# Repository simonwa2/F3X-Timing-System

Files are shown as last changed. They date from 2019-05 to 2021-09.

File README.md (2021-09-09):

# F3X Timing System

## About
The F3X Timing System is a wireless solution for F3F and F3B.  It has been developed and evolved over many years, primarily in response to a need to simplify event timing and management in Western Australia.  In recent years systems have been built for individuals and clubs outside of Australia.

### Simple System for Training Example
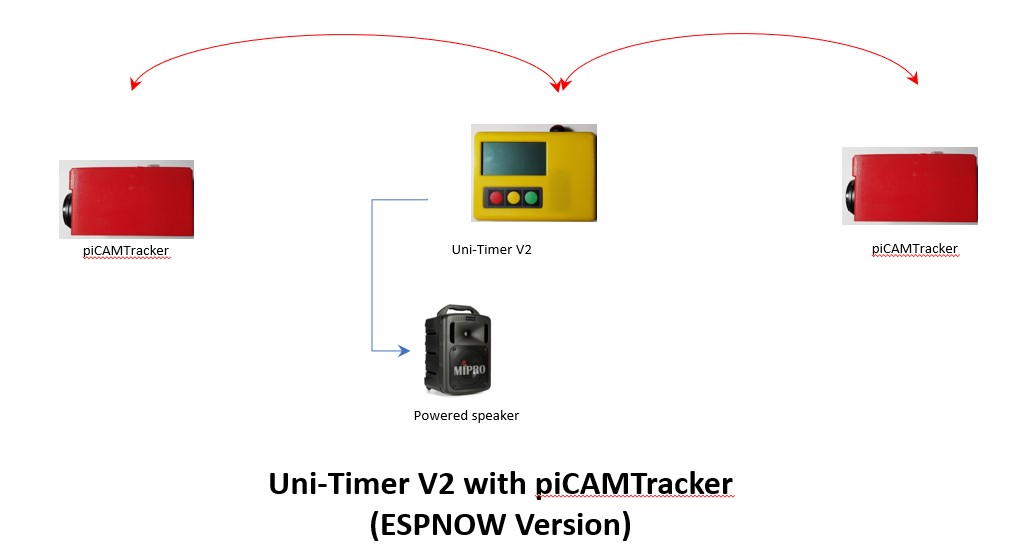
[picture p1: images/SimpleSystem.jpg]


### Full System Example
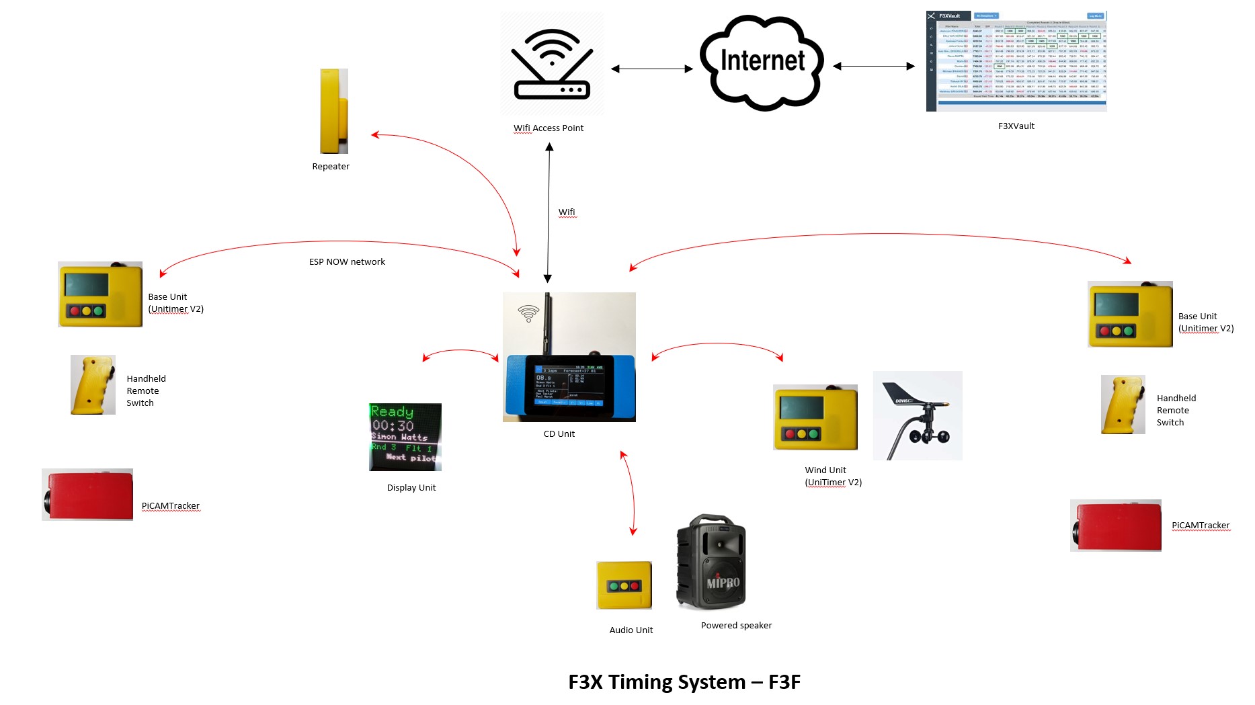
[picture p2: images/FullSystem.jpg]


***
## News

### 19 January 2021
**Transition to ESP NOW radio link.**  Development of a new radio link between modules is nearing completion.  It utilises the ESP NOW protocol available on ESP8266 and ESP32 processors.  ESP NOW provides significantly lower latency and hardware cost than the Xbee modules that the timing system has used for many years.
Existing timing system units will be able to be upgraded to ESP NOW via a plug-in module that replaces the Xbee.  New units have also been developed that utilise ESP NOW.

A short video demonstrating the system is available :
https://www.youtube.com/watch?v=c-oyRrp0d6k&feature=emb_logo

The video also shows the new UniTimer V2 which is a major upgrade from the original UniTimer with an improved and larger display.

Upgrade modules and new units will available from March 2021 (subject to successful contest testing of ESP NOW in February).

***
## Timing system Units

### CD Unit
Used to time and manage contests (pilots, rounds, flights). 
Provides announcements for countdowns, turn signals and flight time. 
Works with f3xvault (via wifi) for data download and upload.  Has
anemometer integration for wind speed and direction. Links to base,
audio and wind units for completely wireless operation.  Uses a high
brightness colour touchscreen for operation.  As well as piCAMTracker,
it also works with MotCam.

Key Features:
* Size: approx 180mm x 85mm x 34mm
* Weight: about 400g
* Power: 2 x 18650 batteries (removeable).
* Display: 4.5 inch high intensity colour touchscreen
* 2.4GHz local network (xbee) for connectivity to external units such as base units or piCAMTracker 

Timing functions:
* flight timer - displayed and announced flight states, countdowns, turn beeps and count, flight time announcement at the end
* lap timer - displayed and announced turn beeps and lap times
Event functions:
* integration with F3XVault - search and download events and upload flight data
* create rounds - set flight order
* run the flights
* all flight data saved to sd card
Anemometer support:
* direct connect David or Peet Bros anemometers or connect to Wind unit for wireless wind data
Compatibility with camera systems:
* MotCam (with F3X Base unit)
* piCAMTracker (with the pi hat)
Audio:
* line out to connect to powered speaker or wireless conenction to Audio unit
Firmware updates:
* by usb upload and sd card

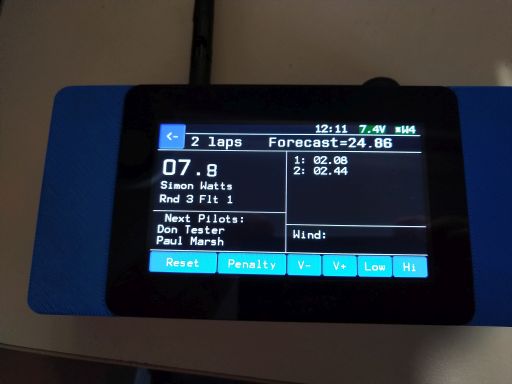
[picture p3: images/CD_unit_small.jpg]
CD Unit


### Uni-Timer V2
Cutdown version of CD unit.  Provides announcements for
countdowns, turn signals and flight time.  Links to base units for
completely wireless operation (and audioand wind in the near future). 
But (at the moment) does not manage contests and does not link to
f3xvault.  Only has a small screen, but provides web pages for extending
capability to smart phones.  Also much cheaper than CD Unit.  It was
originaly intended to be only used for training (particularly with
piCAMTracker), but now my intention is to extend it to full contest
management as well.

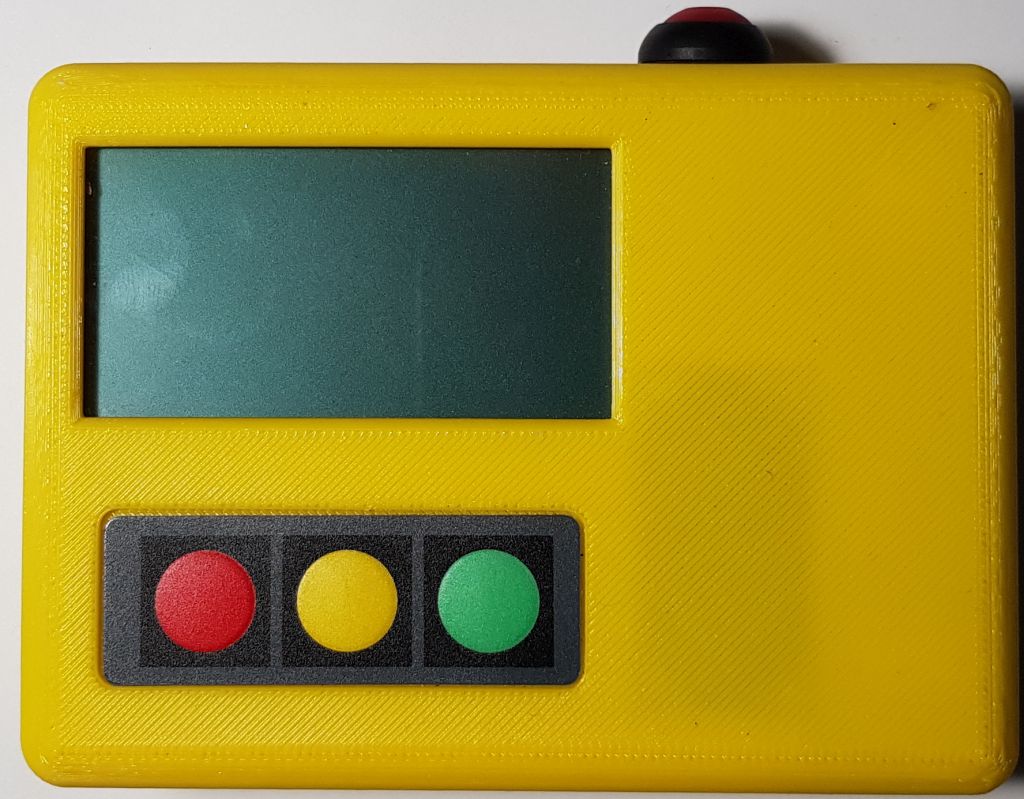
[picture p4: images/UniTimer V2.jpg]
UniTimer v2


### Repeater
Range extender for the local network that links the units.  Placed on a pole near the centre of the course.   

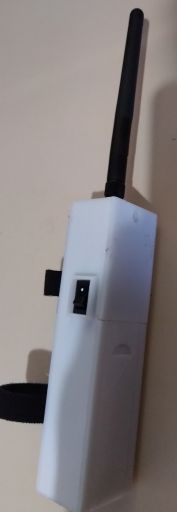
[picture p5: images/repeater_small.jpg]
Repeater


### Audio
Wireless audio with line out for connecting to a powered speaker.

### Display
Wireless large panel LED display for showing flight data to other pilots and watchers. High brightness colour display.  Two versions:
* 400mm x 400mm witha resolution of 64 x 64 pixels
* 260mm x 130mm with a resolution of 64 x 32 pixels

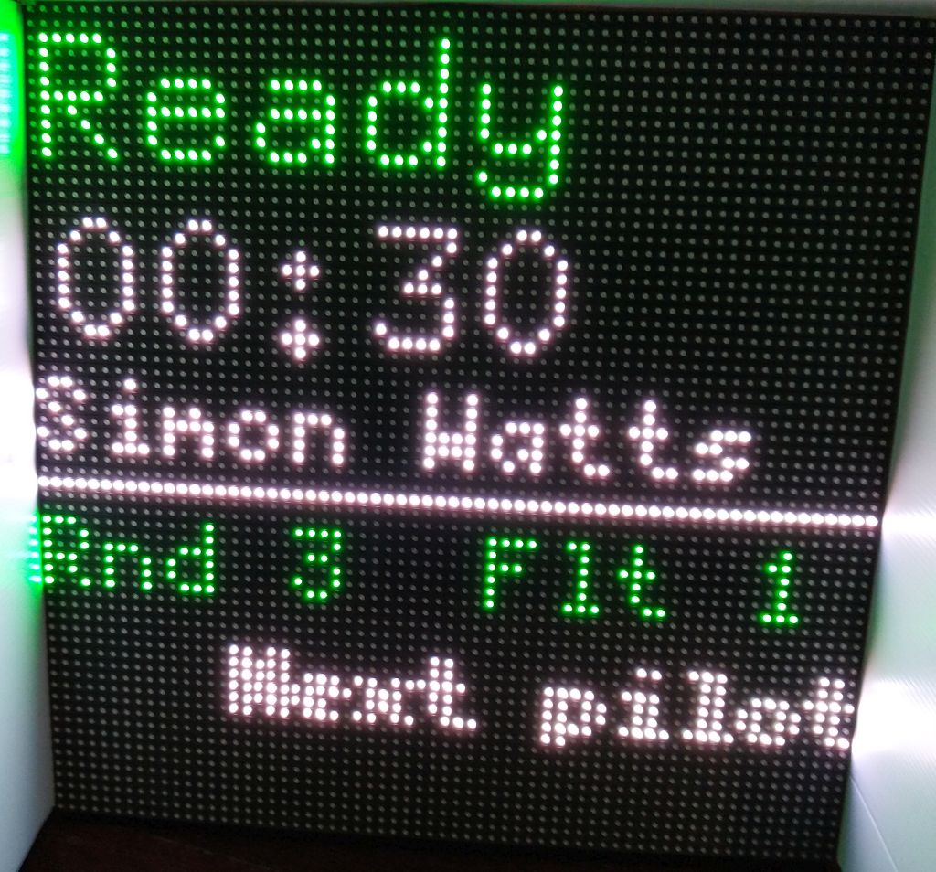
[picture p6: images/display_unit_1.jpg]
Display


## Supported Camera Systems

* Motcam
* piCAMTracker

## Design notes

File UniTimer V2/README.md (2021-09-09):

### Uni-Timer V2
Cutdown version of CD unit.  Provides announcements for
countdowns, turn signals and flight time.  Links to remote units (bases, wind, audio) for
completely wireless operation. Features a larger and more ledgible display than UniTimer V1
The unit can be used for CD functions, Base switch or wind unit.

Key Features:
* Multi-funtion device that can operate as any of:
  * CD Unit
  * Base Unit
  * Wnd Unit
* Size: approx 120mm x 90mm x 30mm
* Weight: about 200g
* Power: removable 18650 LiIon. Expected to last at least 8 hrs between charges.
* Display: 2.4 inch
* 2.4GHz local network (ESP NOW) for connectivity to external units such as base units or piCAMTracker (can also be fitted with Xbee for backwards compatibility)
* Works with the Handheld Remote Switch
* Socket for external (wired) switch
* Tripod mount

Timing functions:
* flight timer - displayed and announced flight states, countdowns, turn beeps and count, flight time announcement at the end.  Auto restart option.
* lap timer - displayed and announced turn beeps and lap times

Compatibility with camera systems:
* MotCam (with F3X Base unit)
* piCAMTracker (with the pi hat)

Audio:
* line out to connect to powered speaker

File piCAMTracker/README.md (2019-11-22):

# Introduction

piCAMTracker is a Raspberry Pi camera based crossing detection system developed by Axel (Barney) Barnitzke.  Details of the system are available here:

https://github.com/barney-NG/piCAMTracker

To connect piCAMTracker to the timing system, a plug-in board (pi hat) was developed.  The board provides the radio link and also power management for the Raspberry Pi.  Details are on Barney's GitHub pages here:
here:

https://github.com/barney-NG/piCAMTracker/wiki/PCB-Hat

# Details

## Power Management
The board uses a switching regulator to provide 5V to the Raspberry Pi.  The input voltage can be between 6V and 36V.  Three 18650 Li Ion batteries in a 3S configuration works well.
A slide switch controls power.  When switched to The Off position, a signal is sent to the Raspberry Pi to do a safe shutdown.  Power is removed several seconds later.

## Radio Link
An Xbee radio module is used for the 2.4GHz link to the timing system.  The link is bi-directional and allows the timing system to query the unit for useful data such as battery voltage and signal strength.

## Turn signalling
Two turn signals are sent:
* piCAMTracker Turn signal
* External switch.  An external switch can be connected to the CMD3 and GND pads on the expansion port.

## Expansion Port
The expansion port provides the following signals:
* +3.3V
* GND
* CMD1 (Input)
* CMD2 (Input)
* CMD3 (Input) used for external switch and sent to timing system by Xbee
* TURN (Output) from piCAMTracker)
* CUT (Output) from piCAMTracker)

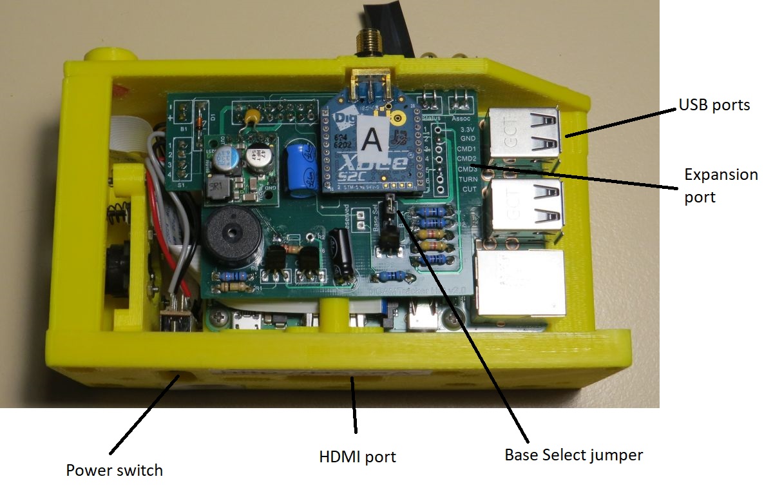
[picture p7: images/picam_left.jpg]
piCAMTracker pi Hat


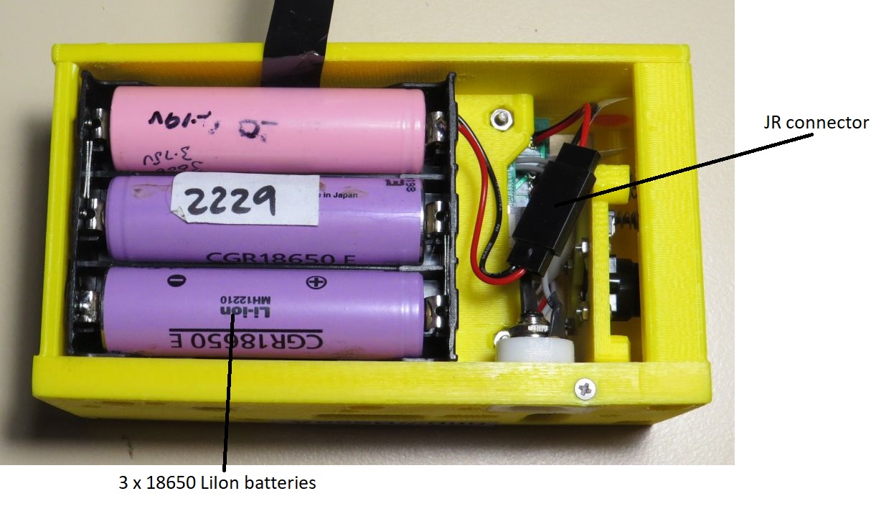
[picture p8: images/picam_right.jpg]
piCAMTracker battery pack


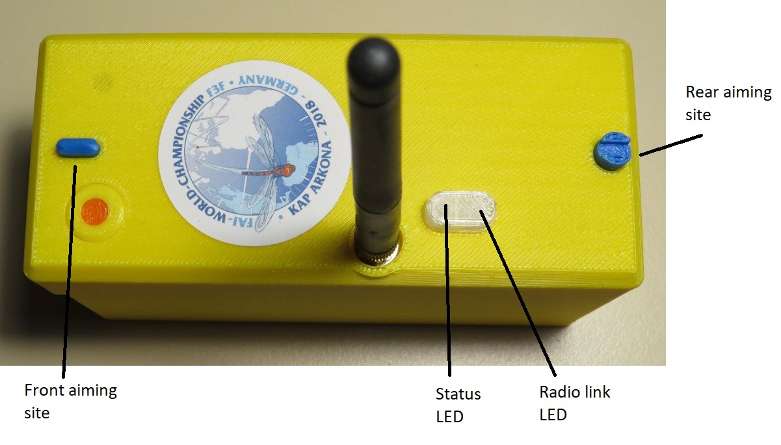
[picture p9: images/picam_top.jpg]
Top View


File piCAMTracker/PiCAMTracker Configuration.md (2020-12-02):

# PiCAMTracker Configuration

This section deals with setting up piCAMTracker with the pi Hat installed and connecting to one of the F3X timing system units (CD, Team or UniTimer).

The picam unit, as supplied, is configured for testing done in Western Australia and needs configuring for your local wifi and country specific settings (keyboard, language, timezone etc).

The initial configuration requies you to connect a mouse (USB), keyboard (USB) and monitor (HDMI). A TV could be used if you don't have a computer monitor.

One the unit has been connected to your home wifi, then it wil be possible to remotely connect to it using VNC Viewer on your computer.  The mouse, keyboard and monitor are then no longer required.

## Connecting the mouse, keyboard and monitor
There are four USB ports at the rear of the Raspberry Pi.  The HDMI video port is accessible from the underside of the case.

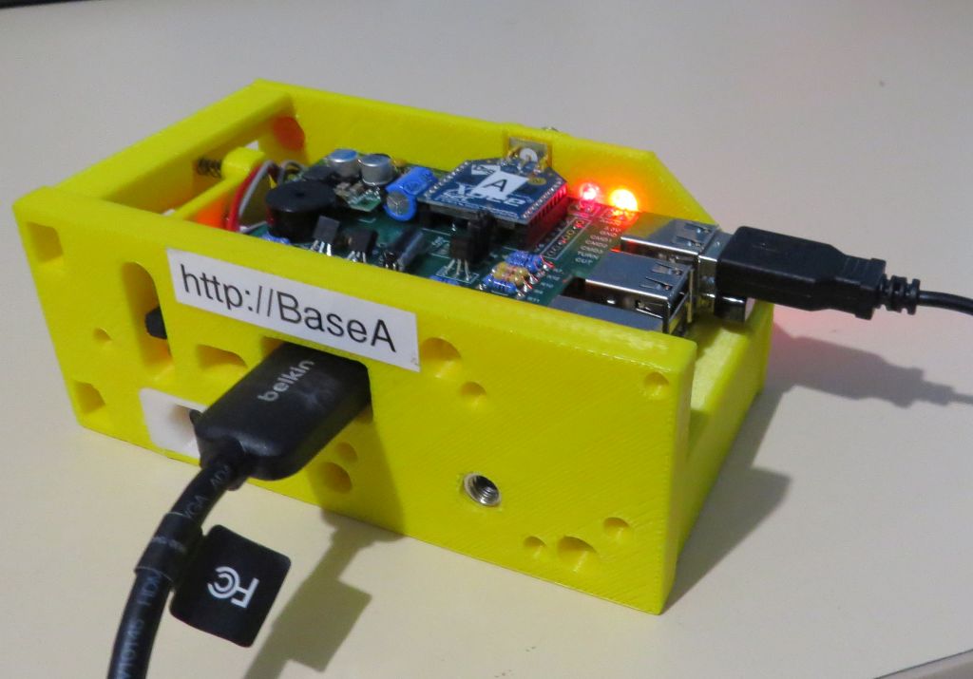
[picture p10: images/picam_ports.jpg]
USB and HDMI


## Configuring localisation settings
Power on the unit (with the mouse, keyboard and monitor connected).  The monitor will show the startup process and then a display similar to Microsoft Windows.  The mouse should be active.
* Use the mouse to select the Raspberry Pi Configuration menu:
** Preferences / Raspberry Pi Configuration
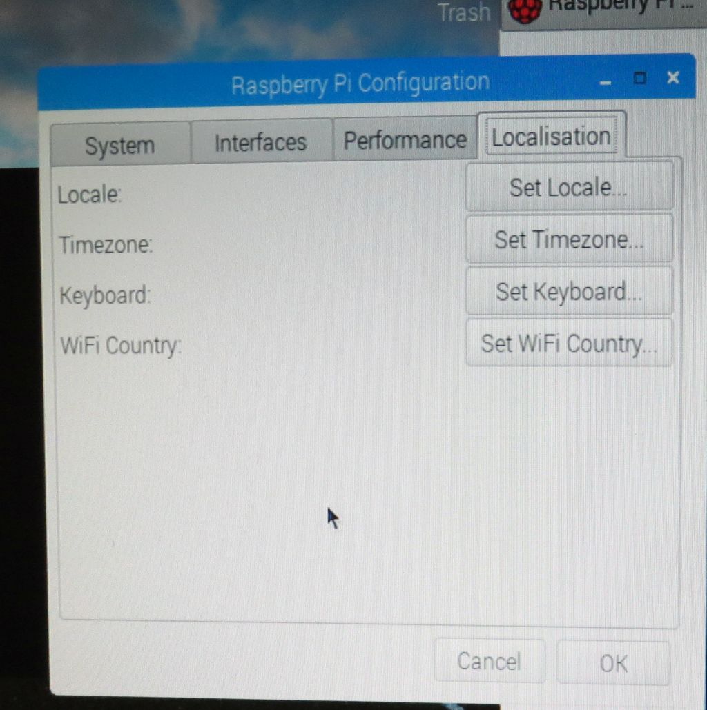
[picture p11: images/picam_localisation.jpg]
Localisation


* Select the Localisation tab then in turn set:
** Set Locale
** Set Timezone
** Set Kyboard
** Set Wifi Country
* Click on OK and agree to a restart when prompted

Note that the camera view will partially cover the configuration window.  You can drag the window to one side to see it better.

## Passsword and Hostname
* Hostname has been preset to either "CamA" or "CamB".  This is what will show as the name on a web page and in VNC.
* Password has been preset to "pct".  Required when accessing the unit via VNC.

You change these to if you want from the Raspberry Pi Configuration  / System tab.

## Setting up wifi
  On the bottom right of the display is the wifi status:

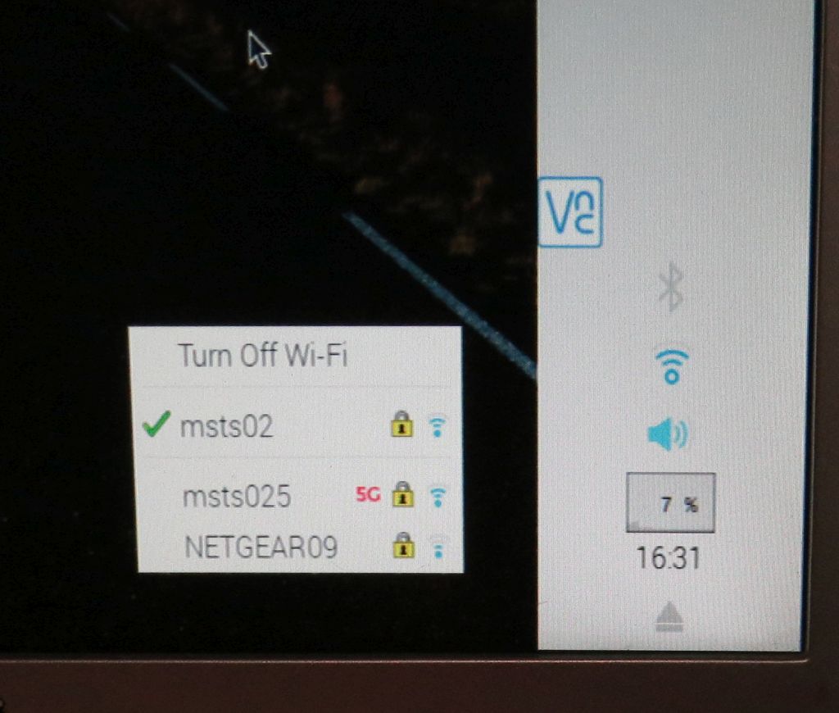
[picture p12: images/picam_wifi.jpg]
wifi

  
* Click on the wifi symbol and the unit will search for available wifi routers
* Select your wifi router and enter the password

This should be done for your home wifi and also any hotspot/router that you will use at the slope - e.g. your mobile phone.

## VNC Viewer
VNC Viewer is a program that allows you to remotely access teh Raspberry Pi from a computer.  This removes the need to connect a monitor, mouse and keyboard.  For this to work the piCAMTracker unit and teh coputer must be conencted to tehsame wifi network, e.g. your home wifi.

VNC is already enabled on the Raspberry Pi.

Download VNC Viewer from here:
https://www.realvnc.com/en/connect/download/viewer/

To connect to the piCAMTracker unit:
* turn power on
* open VNC Viewer on your computer
* enter the hostname (e.g CamA) or IP address (e.g. 192.168.0.22) of your picamTracker unit in the VNC address bar
* VNC Viewer will attempt to conenct to the unit.  You will be prompted for the login name and password.  The login name is "pi" and the password is "pct" unless you changed it.
* VNC Viewer will then show the Raspberry Pi window and you can control it from your computer.
* Note that the camera view from piCAMTracker is not shown in VNC.

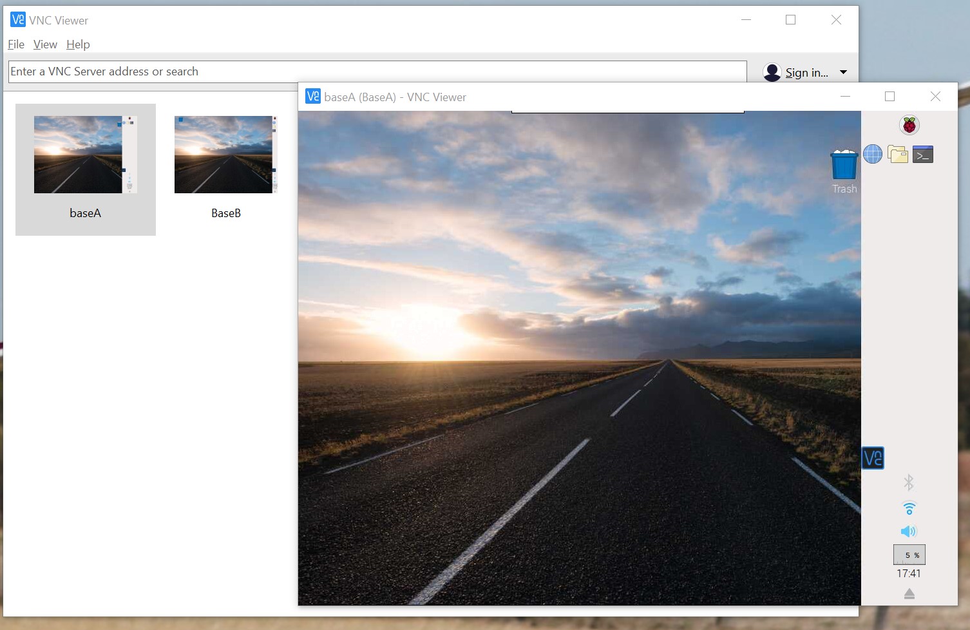
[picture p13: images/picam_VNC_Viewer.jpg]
VNC

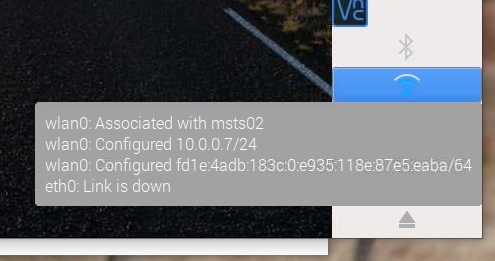
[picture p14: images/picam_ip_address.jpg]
IP Address


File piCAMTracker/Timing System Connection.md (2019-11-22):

# piCAMTracker - Connecting to the Timing System Radio Network

The piCAMTracker unit is provided pre-configured to connect to the timing system.

There are several factors affecting connection:
### Base type
* The xbee radio module has been configured and labelled as either A or B - corresponding to Base A or Base B
* The Base Select Jumper has been set to either A or B.  It must match the xbee configuration

piCAMTracker pi Hat

### Antenna
* A small 2.4GHxz antenna has been provided and screws in on the top of the piCAMTracker unit.  There must be clear line of sight from the antenna to the timing system central unit or repeater.

### Connection LED
The rear LED indicates connection status:
* Solid on - indicates no connection
* Flashing on/off - indicates connected to the radio network.  It may take up to about 30 seconds to connect from when power is applied.

### Timing System
On the timing system unit being used (CD Unit, Team Unit or UniTimer), the relevant camera selection must be enabled.  The timing unit then programs the xbee radio module in piCAMTracker to send data to the CD, Team or UniTimer network address.

Note that you only need to do this process once.  Settings are retained in both the piCAMTracker xbee and in the timing system unit.

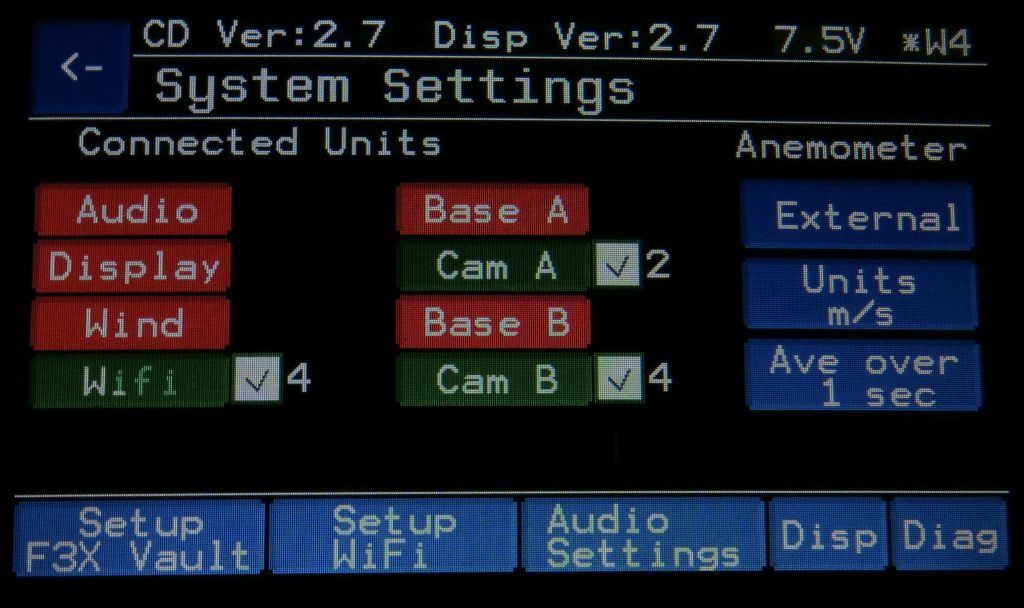
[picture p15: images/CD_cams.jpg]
CD Unit

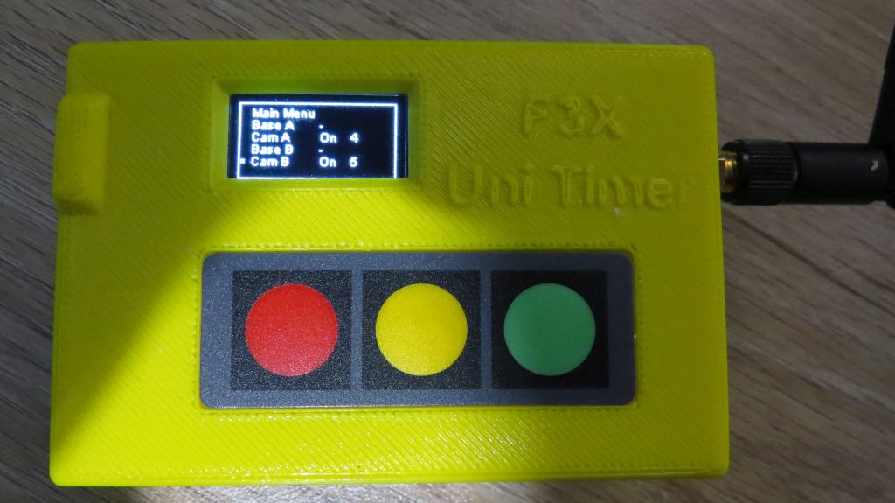
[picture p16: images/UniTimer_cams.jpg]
UniTimer

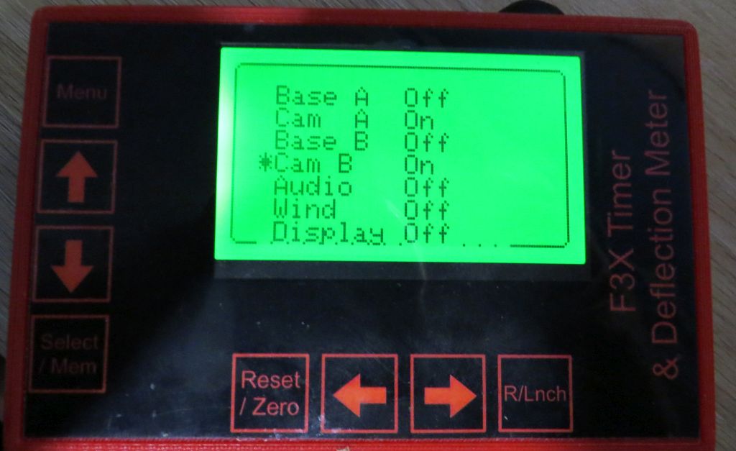
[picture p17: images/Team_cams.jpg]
Team Unit


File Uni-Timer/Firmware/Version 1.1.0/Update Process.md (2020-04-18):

## Process for updating firmware from Version 1.0.5 or 1.0.7 to Version 1.1.0 ##

**1. Get the files:**

* Download the zip file: Uni_timer v1.1.0.zip (select the zip file and then select Download).
* Save the zip file to your computer and unpack it to a convenient location.
* The zip contains the following:
  * Support files:
    * 1 x .mp3 file (point.mp3)
    * 14 x .html files
    * 1 x .css file (style.css)
  * Firmware file:
    * F3X_UniTimer.v1.1.0.bin

**2. Load the new support files:**

* Start Uni-Timer and in a web browser open the Uni-Timer IP address (as shown on the Uni-Timer display)
* From the web page select "Upload new support file"
* Select "Choose file" and find the point.mp3 file downloaded earlier
* Select Upload. The file will be loaded to Uni-Timer and "Upload OK" should be displayed in the browser
* Use the back arrow in your browser to go back to the Support file Upload page
* Repeat the upload process for the other support files 

**3. Upload and apply the firmware file:**

Use the browser back arrow to return to the first web page
* Select "Upload new firmware file"
* Select "Choose file" and find the F3X_UniTimer.v1.1.0.bin file
* Select Update. The file will be uploaded to Uni-Timer (this will take about 20 seconds) after which the Uni-Timer will restart
* When the startup screen appears, press and hold the Red button until Factory Reset appears on the screen.  The unit will apply the default value and start up.

The upgrade is complete.

Note that if you are upgrading from a version earlier than 1.0.5, then make sure that you also upload all of the support files provided with the earlier versions.  Support files are typically .mp3, .html or .csv files.  They were included in the previous version upgrades.

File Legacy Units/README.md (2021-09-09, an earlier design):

The units in these pages are no longer in production,but they are supported for upgrade to the ESP-NOW radio link via a plug-in module.

### Uni-Timer
Cutdown version of CD unit.  Provides announcements for
countdowns, turn signals and flight time.  Links to base units for
completely wireless operation (and audio and wind in the near future). 
Only has a small screen, but provides web pages for extending
capability to smart phones.  

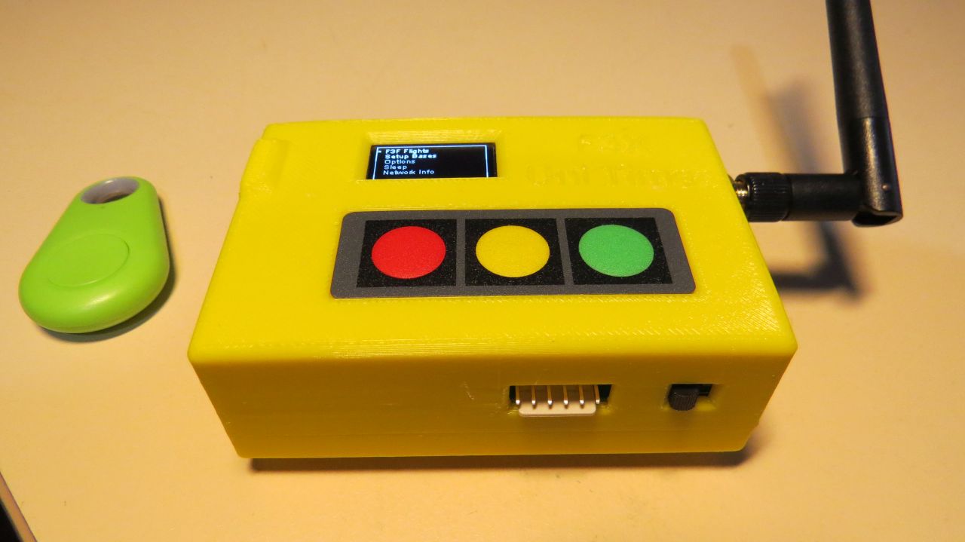
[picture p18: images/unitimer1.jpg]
UniTimer


### Repeater (Xbee version)
Range extender for the local network that links the units.  Placed on a pole near the centre of the course.   Only necessary where the terrain is hilly and the bases do not have clear line of sight of the course center.

Repeater

### Coordinator
Replaced by the Repeater.  Manages the local  network and acts as a range extender for the local network that links the units. 

### Base
Now replaced by UniTimer. Wireless base button with flight data display.

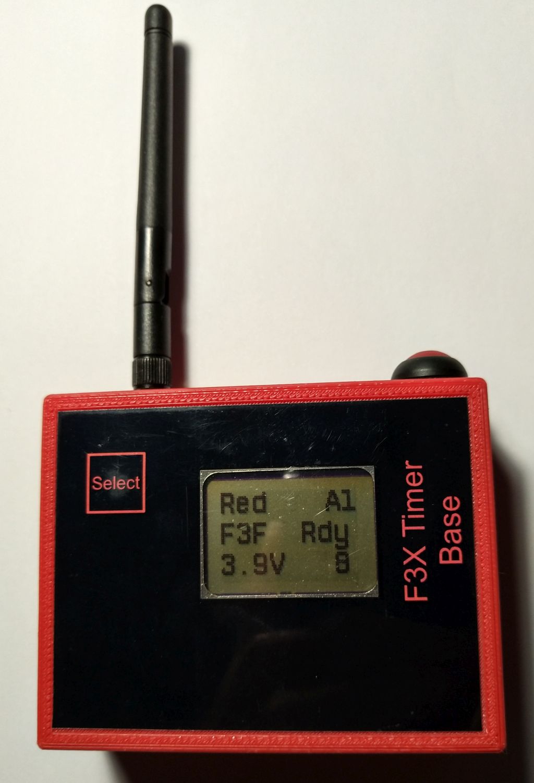
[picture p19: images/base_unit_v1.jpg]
Base


### Wind
Replaced by UniTimer V2. Wireless transfer of anemometer data to CD or UNiTimer units.

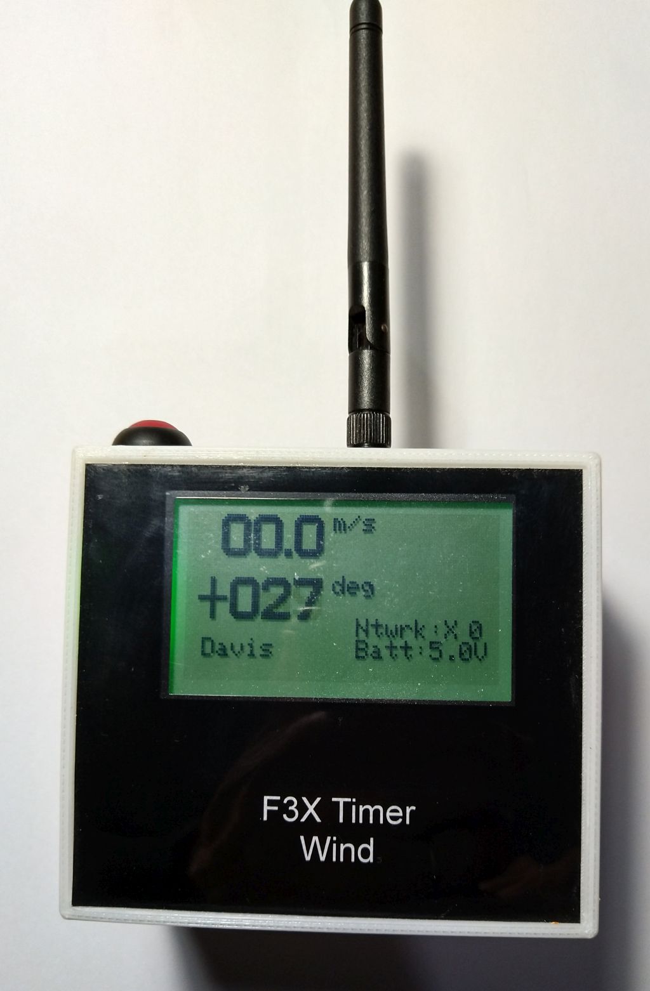
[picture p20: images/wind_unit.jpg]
Wind


### Audio
Replaced by UniTimer V2.  Wireless audio with line out for connecting to a powered speaker.

### Team
The Team unit is designed primarily for F3B.  It provides flight data to support the distance and duration tasks. It can also act as Base A - reducing the number of people required to run the distance task.  The unit also works as a basic F3F timer (no data storage).

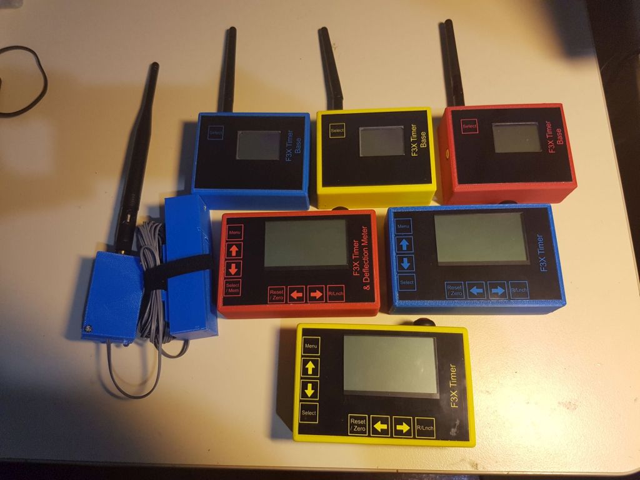
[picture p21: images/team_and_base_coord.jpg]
Team


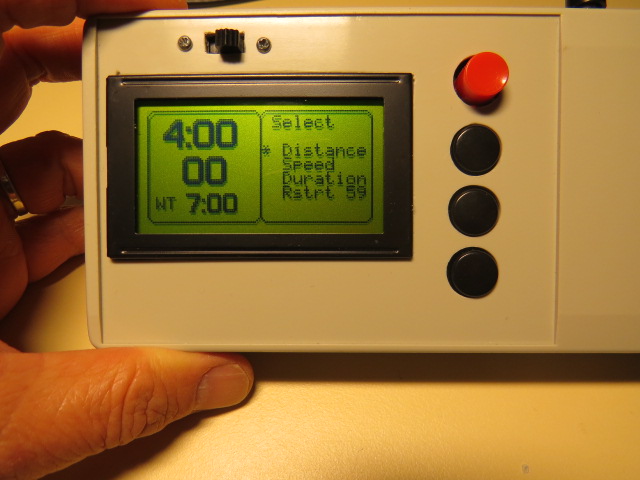
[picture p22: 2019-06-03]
images/f3b_team_v1.JPG

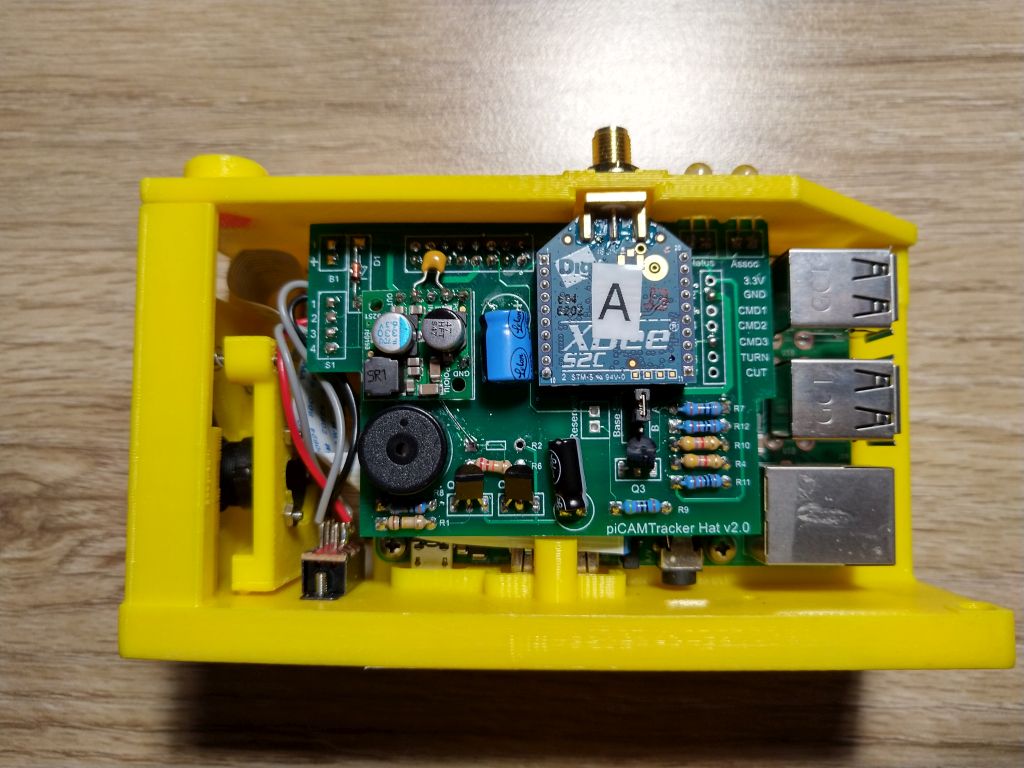
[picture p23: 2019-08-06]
images/picam_piHat.jpg

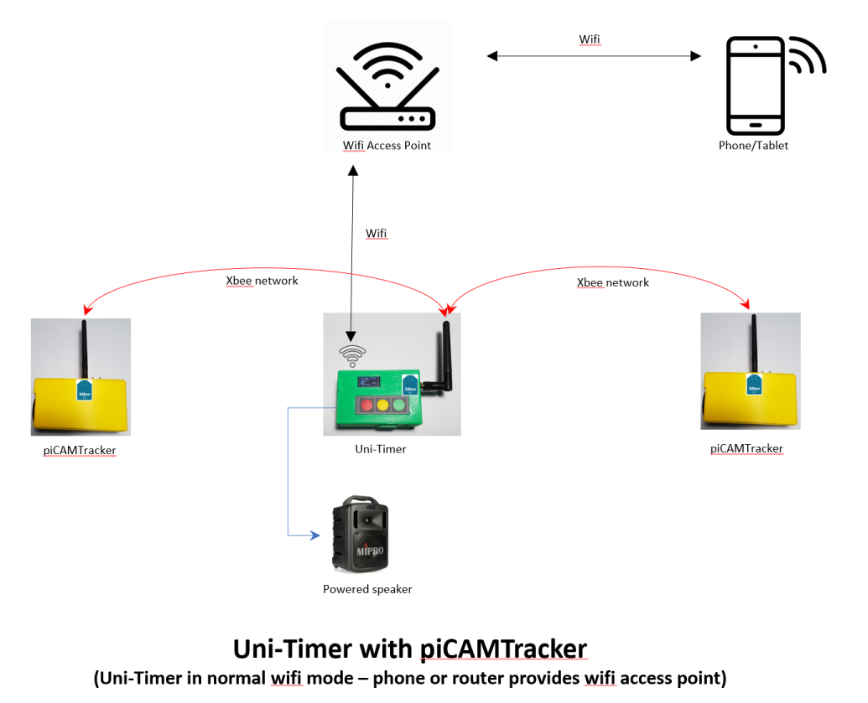
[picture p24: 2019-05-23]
images/UniTimer_normal_wifi_mode1.png

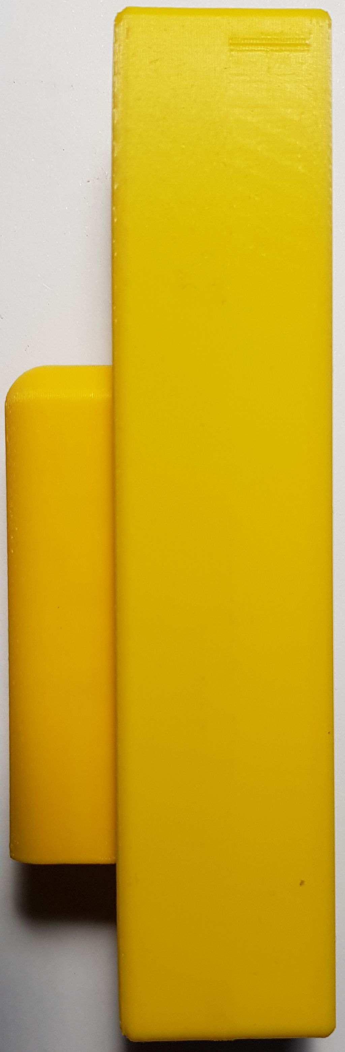
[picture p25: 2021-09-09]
images/Repeater.jpg

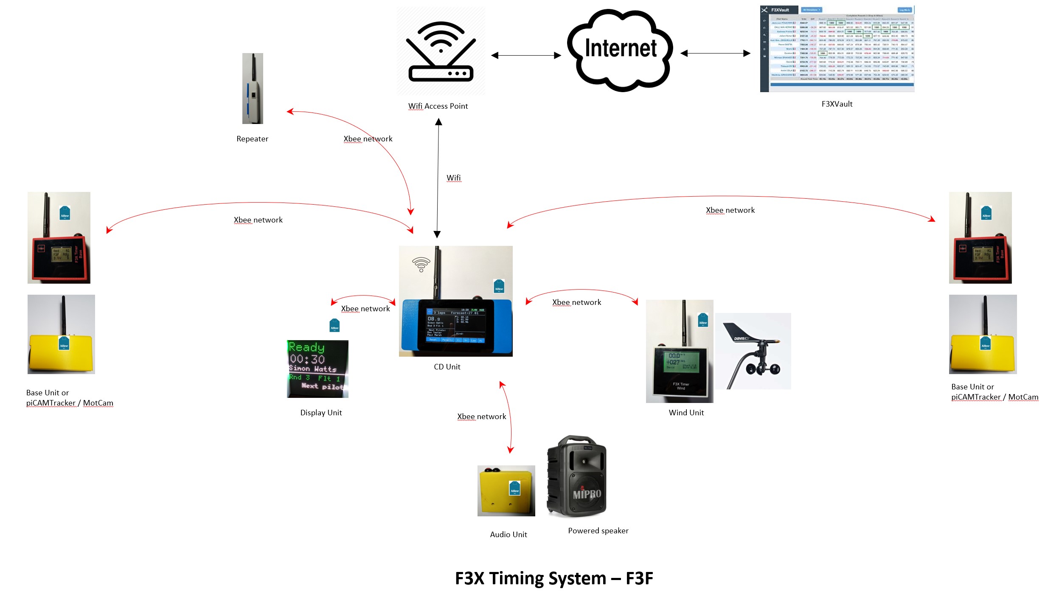
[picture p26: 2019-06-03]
images/f3f_network_1.jpg

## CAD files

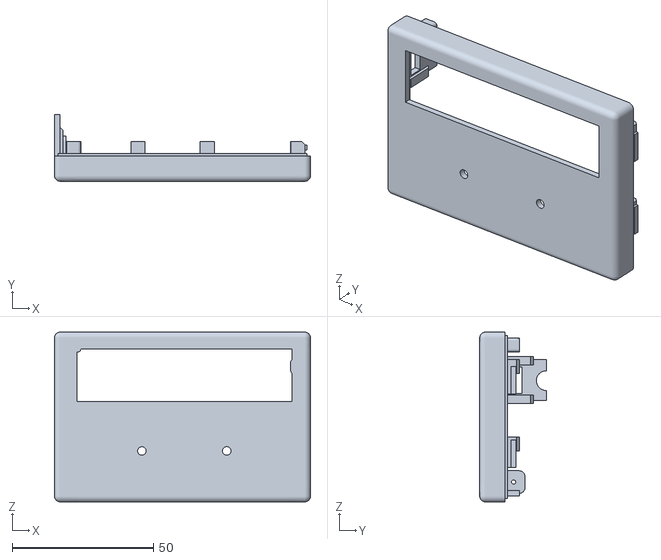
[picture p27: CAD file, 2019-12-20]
Uni-Timer/3D Print files/Version 2/f3x Uni 18650 base V2.stl
90.5 x 23.5 x 60.0

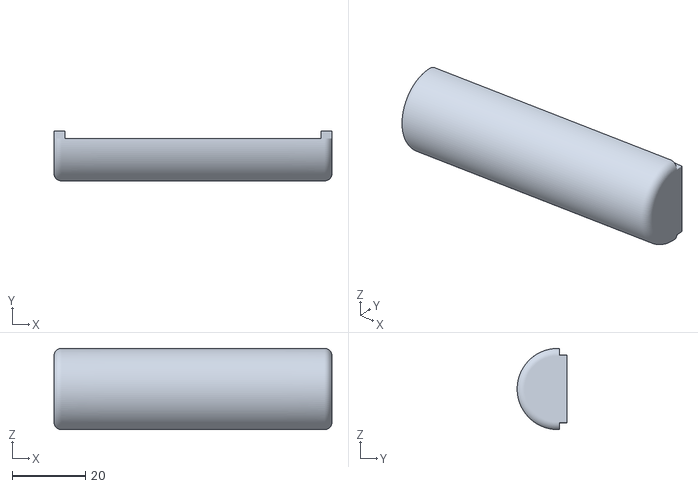
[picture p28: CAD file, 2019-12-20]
Uni-Timer/3D Print files/Version 2/f3x Uni 18650 bulge V2.stl
76.0 x 13.6 x 22.2

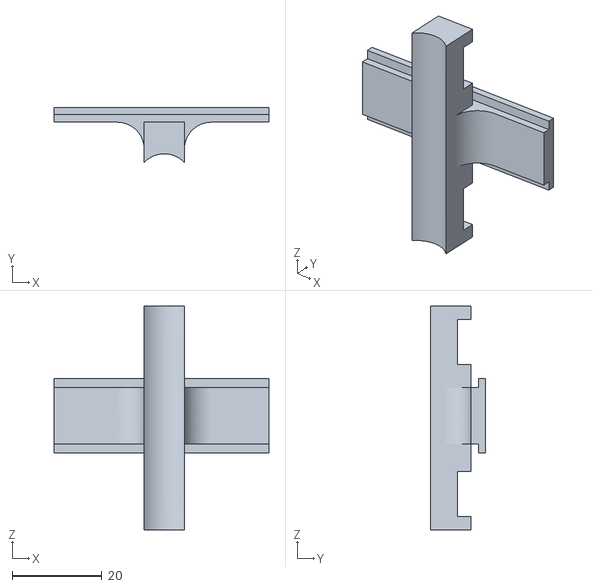
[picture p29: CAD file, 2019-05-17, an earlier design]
Uni-Timer/3D Print files/Version 1/PoleMount.stl
48.0 x 12.3 x 50.0

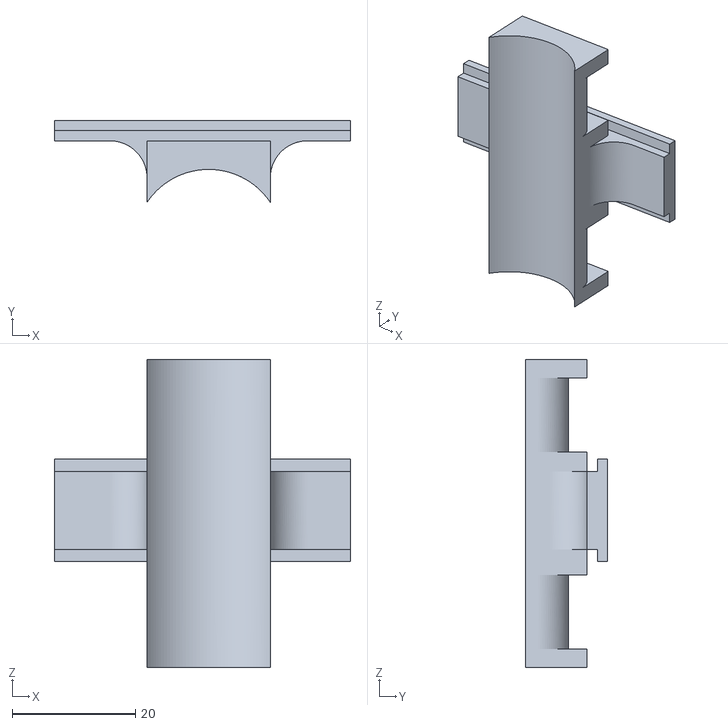
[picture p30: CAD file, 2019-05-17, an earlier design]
Uni-Timer/3D Print files/Version 1/PoleMount24mm.stl
48.0 x 13.3 x 50.0

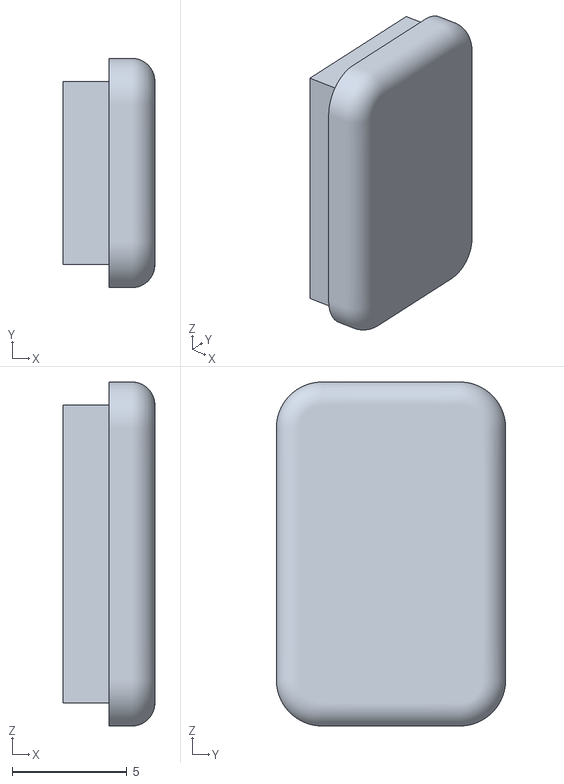
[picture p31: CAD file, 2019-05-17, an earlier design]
Uni-Timer/3D Print files/Version 1/f3x uni usb plug.stl
4.00 x 10.0 x 15.0

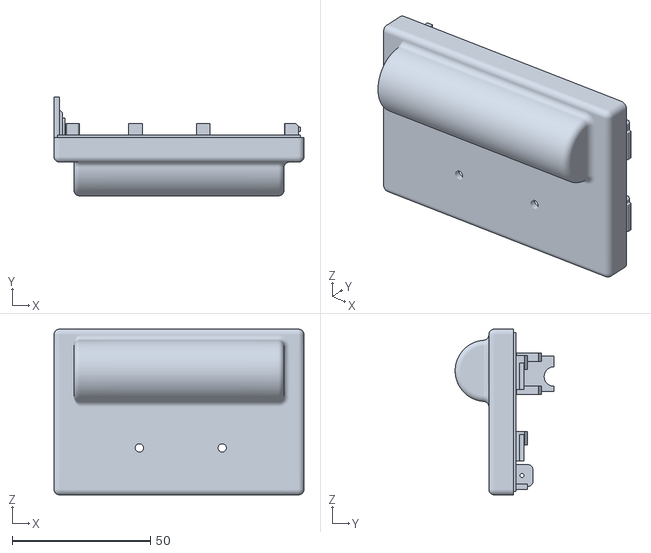
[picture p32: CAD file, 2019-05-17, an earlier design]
Uni-Timer/3D Print files/Version 1/f3x Uni 18650 base.stl
90.5 x 35.7 x 60.0

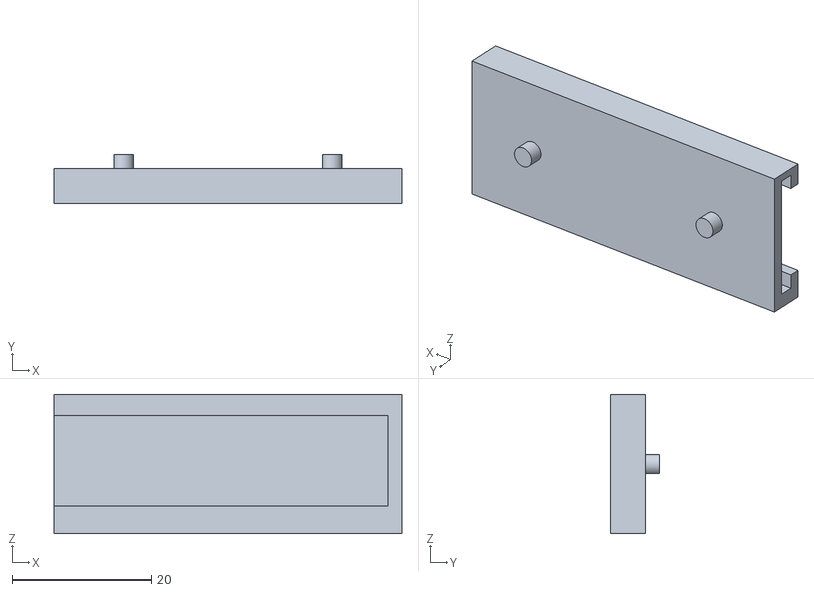
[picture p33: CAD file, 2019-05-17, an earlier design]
Uni-Timer/3D Print files/Version 1/UniMount.stl
50.0 x 7.00 x 20.0

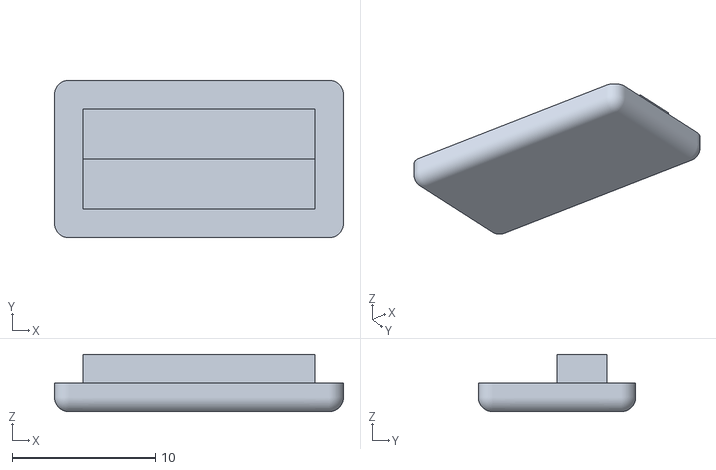
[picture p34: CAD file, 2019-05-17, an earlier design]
Uni-Timer/3D Print files/Version 1/f3x uni ext plug.stl
20.2 x 11.0 x 4.00

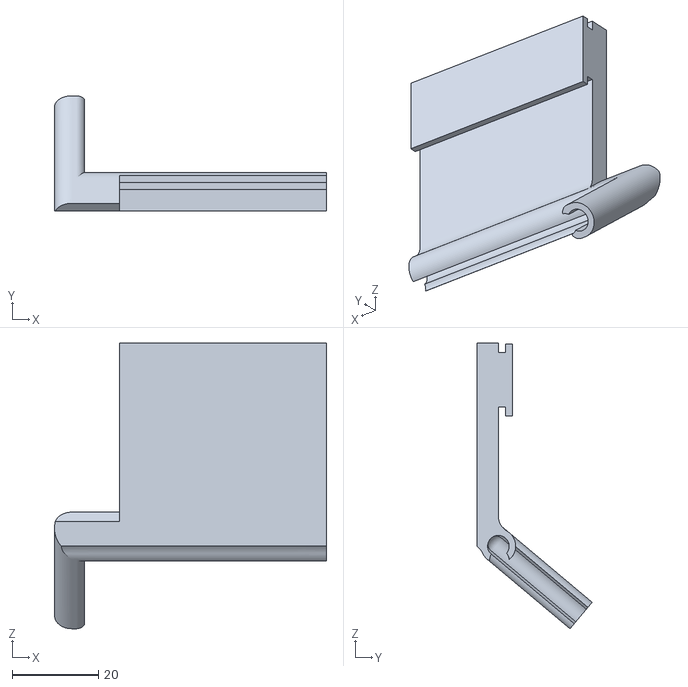
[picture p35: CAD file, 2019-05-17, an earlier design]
Uni-Timer/3D Print files/Version 1/DS16 mount.stl
63.0 x 26.7 x 66.1

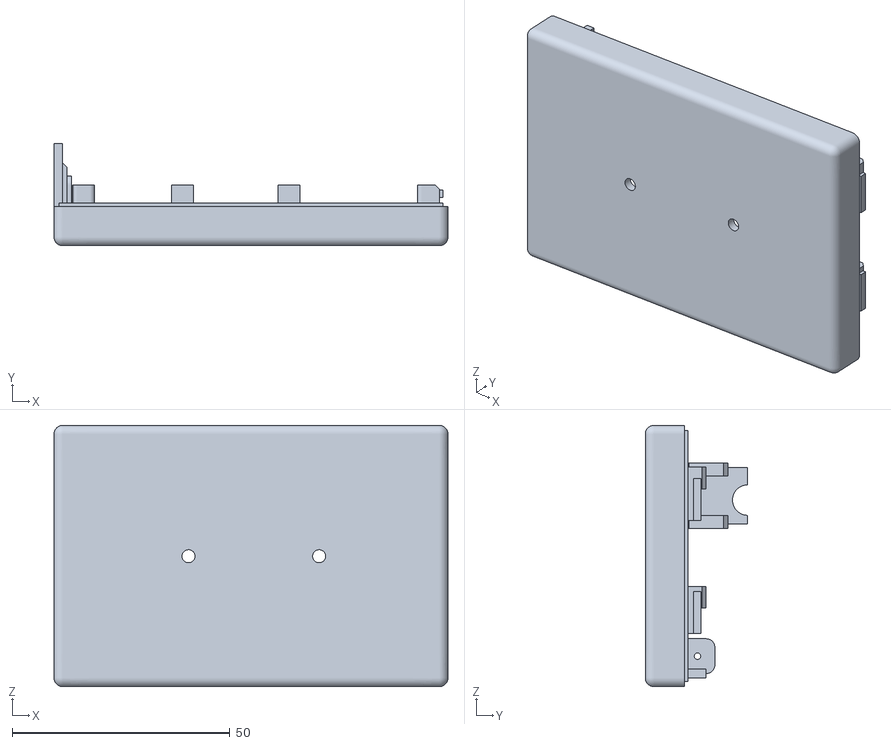
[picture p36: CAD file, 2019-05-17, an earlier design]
Uni-Timer/3D Print files/Version 1/f3x Uni base.stl
90.5 x 23.5 x 60.0

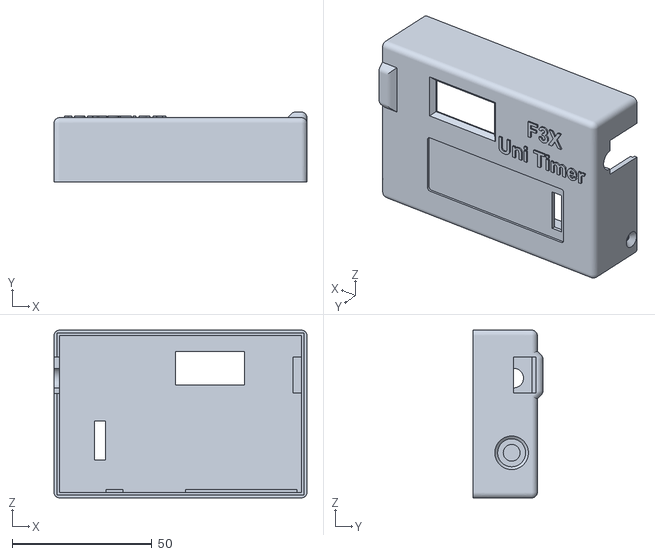
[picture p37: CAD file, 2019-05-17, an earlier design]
Uni-Timer/3D Print files/Version 1/f3x Uni top.stl
90.5 x 25.0 x 60.0

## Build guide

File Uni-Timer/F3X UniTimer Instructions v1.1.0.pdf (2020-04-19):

- 1 -

# F3X Uni-Timer Version 1.1.0

## Contents

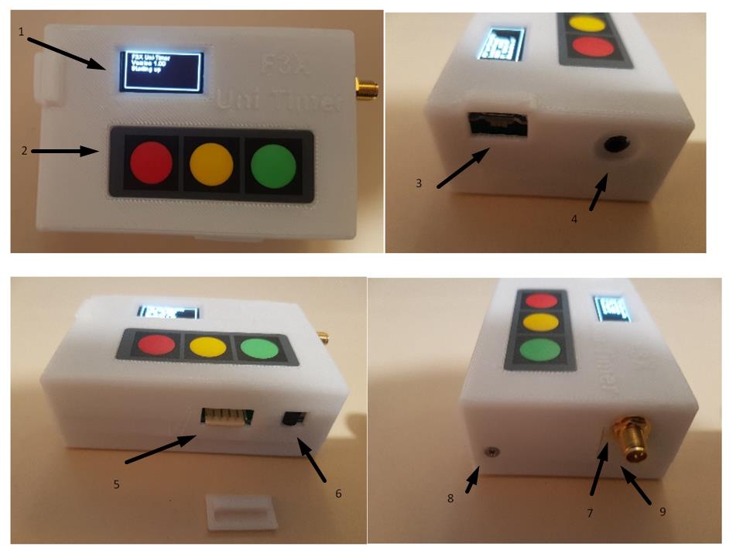
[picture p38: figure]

- 2 -

## 1. Introduction

UniTimer operates as either a central timing unit (CD Unit), a base switch (Base Unit) or a remote audio unit (Audio Unit). It will work with MotCam and piCAMTracker camera systems. It can also be used (as a Base Unit) with the larger touch screen CD Unit. UniTimer also has wifi capability for managing small events and for connectivity to F3XVault for scoring.

## 2. Switches and ports

1. Display
2. Menu and operation switches
3. USB port – connect to phone charger to charge the battery
4. Audio out – connect headphones or a powered speaker
5. Expansion port
6. On/off switch
7. Antenna
8. Case screw
9. Charging port

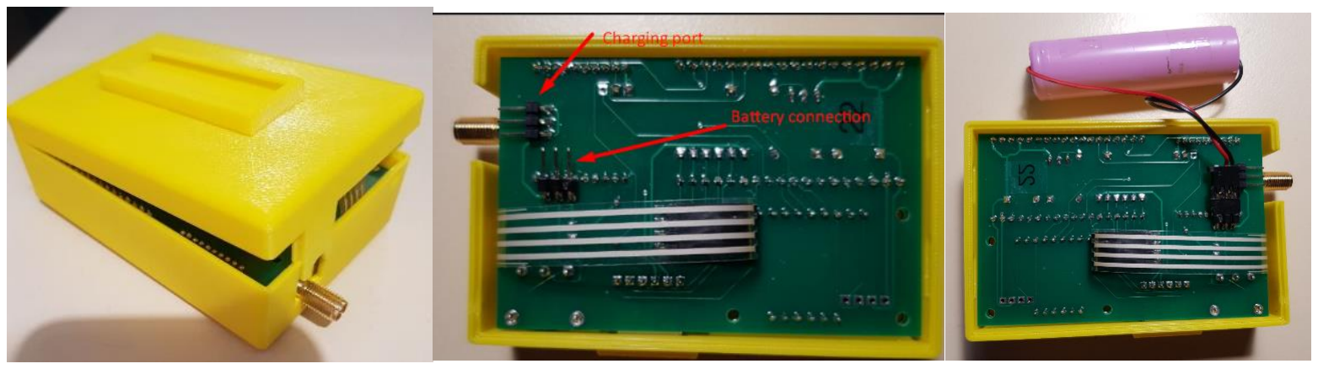
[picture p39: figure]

- 3 -

## 3. Battery

The system is designed to be powered by a single cell 18650 LiIon battery. The unit has been fitted with a 3-pin connector to connect the battery using a JR style plug. The centre pin is positive and the two outer pins are negative.

### Installation

The case must be opened to install the battery. Remove the case screw and antenna nut. The case can then be hinged open from the antenna end. The battery can then be pushed into the recess and held in place with double sided tape if necessary.

### Charging

The unit has a USB charger built in. Connecting a USB power source and turning the unit on will initiate charging. Charge time is approximately 8 hours for a 1,200 mAh battery. Charging is indicated by a red LED visible through the case to the left of the display (not for dark blue cases). The LED has three modes when the USB is connected:

1. Flashing – USB power has been applied, but power switch is off – unit is not charging
2. Solid red – unit is charging
3. Off – battery is fully charged

Note that the unit can be used whilst charging. It will turn on as soon as USB power is connected.

There is also a charge socket next to the antenna connector. This is a three-pin header that a standard JR connector will plug into. The centre pin is positive and the two outer pins are negative. The header is directly connected to the battery so a standard LiPo charger can be used.

### Battery voltage indicator

The battery voltage is visible on the main menu and the flight screens.

- 4 -

## 4. Starting

When powered on, either by battery or USB, the unit will go through start-up stages dependent on its settings:

1. Power on screen
a. Startup
b. Wifi initialisation (if wifi enabled)
2. Information screen – shows web server URL, wifi mode
3. Pressing the yellow button then shows the main menu

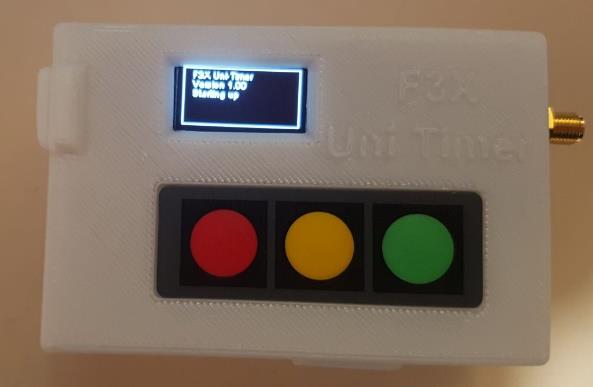
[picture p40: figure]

## 5. Navigation

There are three buttons used to navigate the system:

1. Red – menu exit and flight reset. Factory Reset when pressed on startup screen.
2. Yellow – menu item select
3. Green – menu item navigation and flight start

## 6. Factory Reset

If necessary, e.g. after a major firmware upgrade, a factory reset can be run. This simply resets critical configuration data back to preset values. To run the factory reset, press and hold the Red button once the startup screen appears after turning on power. The screen will then show Factory Reset and restart the system.

## 4. System Menus

### Main Menu

The main menu has the following (in Base Unit configuration the Setup Bases item is not present):

1. F3F Flights – flight menus
2. Setup Bases – base and camera unit selection
3. Options – setup options
4. Sleep – puts the unit into low power sleep mode. Use when charging.
5. Network Info – displays network connection information

### F3F Flights Menu

1. Practice Flights
2. Practice Laps
3. Prac Flight Restart setting

- 5 -

### Options Menu

1. Volume – Cycles through 10 steps by pressing Yellow button
2. Unit Type – CD, Base A, Base B, Audio, or Wind (changing requires a restart)
3. Wifi – Client, AP, or Off (selecting goes to the wifi menu)

### Bases Menu

Allows binding of base or camera units to use with the system.

Binding process

1. Ensure that the relevant base or camera unit is turned on
2. Select the unit in the Base menu. It will show ‘On’ and should also show ‘Linked’ to confirm that binding has been successful and then the signal strength (1-10).
3. This process only needs to be done once. The configuration is saved and subsequent use of the system uses the saved configuration.
4. Units should be deselected if they are not being used (‘-‘ shown next to unit name)

### Wifi Menu

1. Wifi Mode
2. SSID to use
3. Save Setting and Restart

The WiFi type can be selected to be one of:

- Client (UniTimer connects to an access point, e.g. a mobile phone hotspot)
- AP (UniTimer sets up its own access point)
- Off (Wifi is turned off)

For Client mode, the SSID of the wifi router/hotspot to be used must be specified. This can be selected here, but the values to use are setup using the System Settings web page.

A restart is necessary when switching Wifi modes

### Signal indicator

A small Y or N will show in the bottom right of the display on the flights pages and setup menu.
When using the unit as a base unit, this indicates connection to the central timing unit. Y=connected. N=not connected.

- 6 -

## 5. Wifi

### Wifi Modes

The unit has three wifi modes:

1. Client Mode – connects to a wifi access point, e.g. a router or phone set to be a mobile hotspot
2. AP Mode – runs its own access point that other devices can connect to
3. Off – wifi disabled

When in Client or AP mode, devices such as smart phones can connect to the unit’s web pages for information and configuration.

### AP Mode

If AP mode is selected then the unit will start up its own access point called ‘F3X Timer’. To use this:

1. Use a wifi device, e.g. mobile phone to connect to the unit
2. On the phone wifi setup select ‘F3X Timer’ from the available wifi sources
3. In a web browser, enter 192.168.1.4 as the address to use

AP mode must be used for setting up the client mode access point details.

### Client Mode

If Client mode is selected, then the unit will attempt to connect to a local wifi access point using saved credentials. These credentials are stored in a file on the system called ssids.csv. The details (SSID name and password) of up to five access points can be stored in the system. The access point to use is selected in the Options menu.

If the access point is not turned on, not in range, or the credentials have not been set, then a warning will show saying that it is unable to connect. Press the green button to continue. Wifi will not be active.

Further details on setting up Wifi are available here:

https://github.com/simonwa2/F3X-Timing-System/wiki/F3X-Uni-Timer---wifi-modes

and:

https://github.com/simonwa2/F3X-Timing-System/wiki/F3X-Uni-Timer---configuring-for-multiple-wifi-access-points (https://github.com/simonwa2/F3X-Timing-System/wiki/F3X-Uni-Timer---configuring-for-multiple-wifi-access-points)

- 7 -

## 7. Web Pages

The unit has a web server that provides web pages for controlling and viewing flights, and for configuring the system. The address to use is shown on the startup screen.

### Main (Home) page

The home page provides access to events, practice flights and system settings. It is also used to initiate firmware upgrades. The URL address for this page is as shown on the UniTimer Startup and Network Info screens.

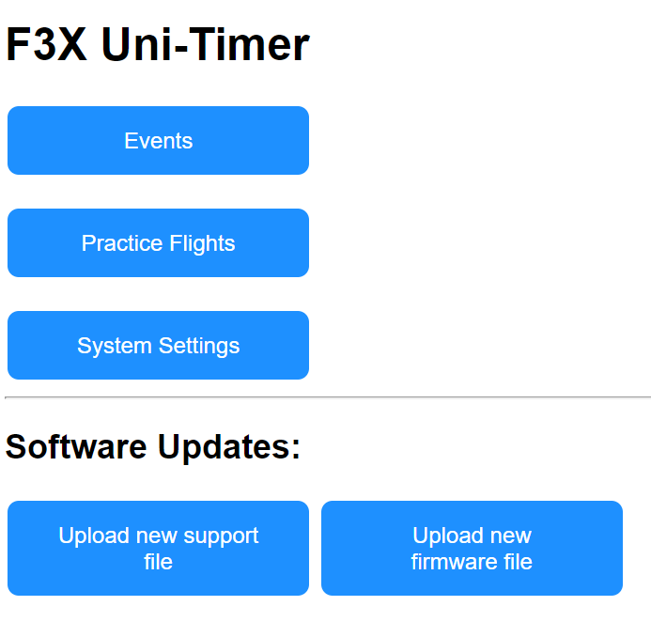
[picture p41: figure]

### System Settings

Allows the configuration of various settings.

- Base Configuration – shows the current base/camera setup
- Volume – shows and adjusts the volume for the audio out socket
- Battery – shows the current battery charge
- Wifi HotSpot – use this to set up credentials for up to to five different wifi hotspots/routers. The hotspot to then use is set in the Wifi Options page on UniTimer. This is applicable only to Client mode. Enter the SSID name and password and select Submit.
- F3XVault User – use this to set your credentials for logging into F3XVault. Required for downloading events and uploading flight data from/to F3XVault. Enter the username and password and select Submit
- Software Updates. Select Upload new support file or Upload new firmware file as directed in the upgrade instructions included with new versions.

- 8

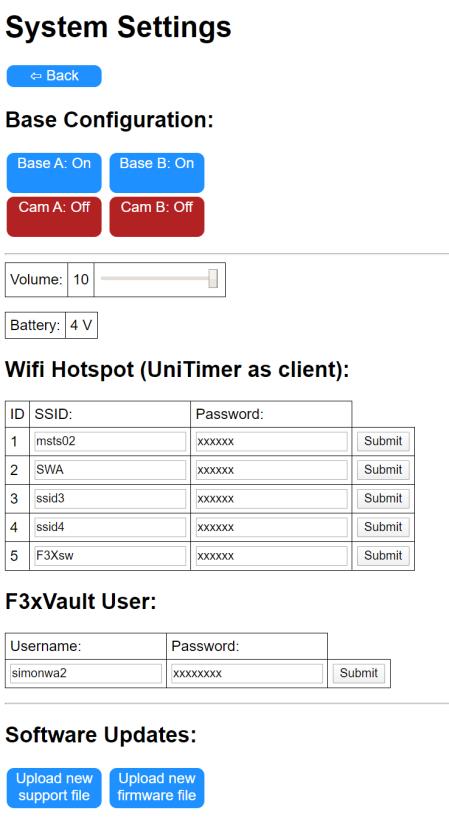
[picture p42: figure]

- 9 -

## 7. F3F Flights

There are three types of flight management:

- Practice Flights – individual F3F flights saved for later analysis
- Practice Laps – continuous laps practice with lap times called out
- Contest Flights – full F3F contests suitable for small events or groups practice

### Practice Flights

Practice flights can be run from the unit interface (LCD display and buttons) or the web interface.

Unit Interface:

- From the Flights Menu:
- Set the desired auto-restart time: manual, 10, 15, 20, or 30 secs
- Select Practice Flights
- Use:
- Green button to start the flight – Pre-Launch, Launched
- Red button to reset the flight
- Yellow button to go back to the Flights Menu
- Flight data: status, time and lap count are shown on the screen
- At the end of a flight, the flight data is saved to internal storage for later retrieval

Web interface

- From the Practice Flights web page:
- Set the desired auto-restart time: manual, 10, 15, 20, or 30 secs
- To run the flight use:
- Start Flight to start the flight – Pre-Launch, Launched
- Reset Flight to reset the flight
- Flight data is dynamically displayed as the flight progresses. Note that updating the web page is a lower priority than flight signalling and timing and may be delayed slightly.
- To access flight data use:
- Download Results to download a .csv file to your computer. The .csv file can be viewed in a text editor or a spreadsheet (Excel). Note that the download does not work with Android phones (iPhone not tested). There is only one file and flights are appended to it after each flight.
- Delete Results to clear the results file.

Manual or automatic start of the next flight can be set on the F3F Flights menu. The options are 10s, 15s, 20s, 30s or manual start. If an auto start time is selected then, at the end of a flight, a pre-launch countdown will commence. This gives the pilot time to fly back to the centre of the course n time to get the Launched signal and commence the 30s climb-out to start the flight,

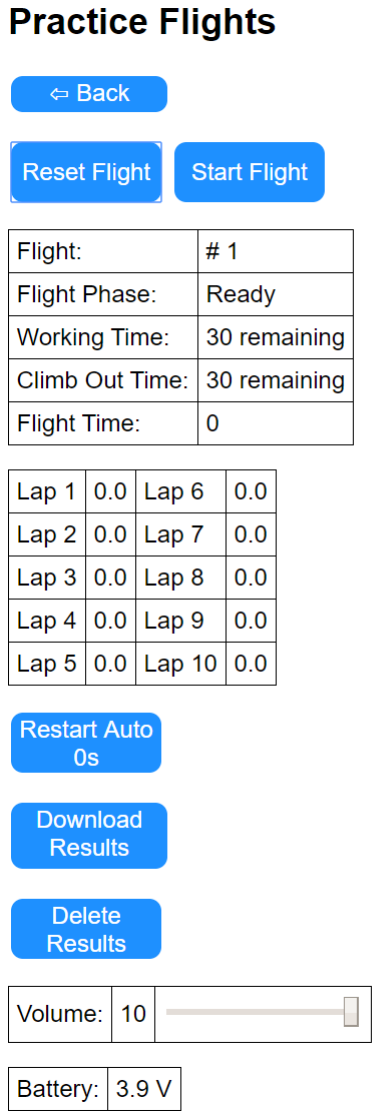
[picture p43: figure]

- 10 -

### Practice Laps

Practice laps can only be run from the unit interface (LCD display and buttons). It provides for continuous lap timing with each lap time being called.

- From the Flights Menu:
- Select Practice Laps
- Use:
- Green button to start the flight
- Red button to reset the flight
- Yellow button to go back to the Flights Menu

<image>

### Events Flights

Contest flights can only be run from the web interface. Two types of events can be created:

- Downloaded from F3XVault. Event created in F3XVault and pilots assigned. Rounds created in UniTimer. Flight times can be uploaded to F3XVault for scoring. Flight data is also available to be downloaded to a computer for analysis.

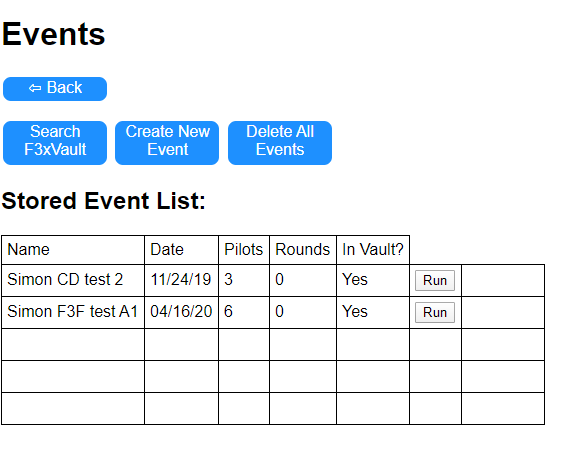
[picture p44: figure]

- 11 -
- Manually created on UniTimer. Flights cannot be uploaded to F3XVault, but flight data is available to be downloaded to a computer for analysis.

To run events, select Events from the home page. This open the Events page where you can add or run events and download event flight data.

### F3XVault Event

Note that to search F3XVault you must have set your F3XVault username and password on the System Settings page.

To add an F3XVault event:

- select Search F3XVault - a search page will open
- set the country code and range of months to search
- select Search Vault – a list of available events will load
- select Load for the required event – the event will be loaded to memory and the Events page will open.

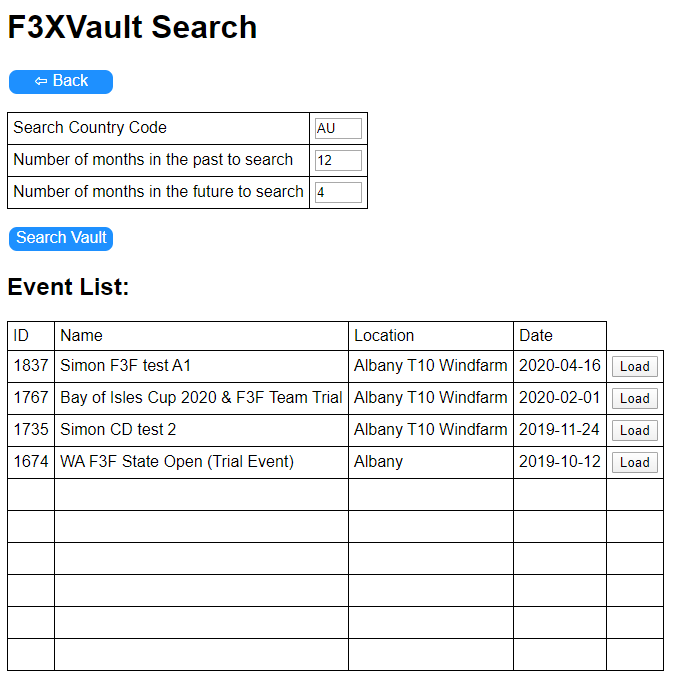
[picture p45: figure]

- 12 -

### Manual Events

To manually create an event:

- Select Create New Event on the Events page – the New Event page will open
- Complete the event name, location, date and number of pilot fields.
- Update the pilot names for the number of pilots that will compete (or leave as is)
- Select Create – The event will be created and the Events page will open

### Running an Event

- Select Run for the event from the list of stored events on the Events page.
- The Rounds page opens. For a new event, no rounds will be available and at least one must be created to start flying:
- Select New Round – the New Round page opens
- Set the number of rounds to create
- Set the number of back to back rounds. This is useful for small events where a pilot flies two or more consecutive flights without landing
- Adjust the flight order, if necessary, using the Up and Down buttons for each pilot. Note that flight order will be retained for future rounds.
- Select Create New Round to create the new round(s). The rounds will be created and the Rounds page will open with the first round selected

- 13 -

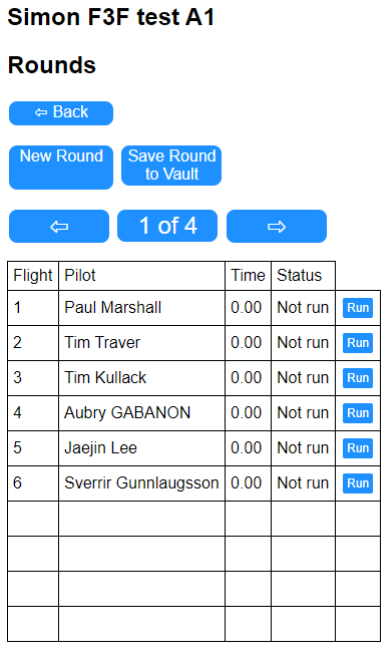
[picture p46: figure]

- The round to fly can be selected using the left and right arrow buttons.
- Select Run for the first pilot to fly, e.g. Round 1, Flight 1. The Flights page will open and the UniTimer LCD display will show the flight data screen. The flight is now ready to start.
- Select Start Flight on the web page or press the green button on UniTimer to start the 30 second pre-launch countdown.
- When the aircraft is launched, select Start Flight on the web page or press the Green button on UniTimer to start the 30 second launch countdown.
- UniTimer now responds to Base A and Base B button presses for the Out and base turn signals.
- During the flight the web page and the UniTimer display will show the flight status, countdowns and flight time. The web page will also show the individual lap times and the next two pilots to fly.
- At any point in the flight up until it is finished, Reset Flight or the Red button can be pressed. The flight will be reset back to the start point.
- After the flight has finished, selecting Start Flight or the Green button will advance to the next flight.
- If a pilot has to fly out of order then the <= Prev or Next => buttons can be pressed to move through the flight order. Or return to the Rounds screen to directly select the round and flight to fly.

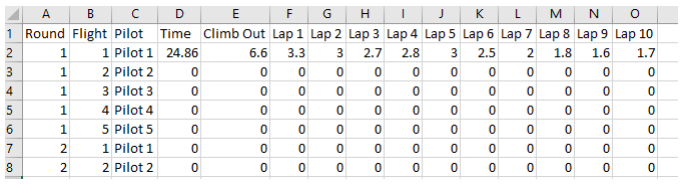
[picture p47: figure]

- 14 -

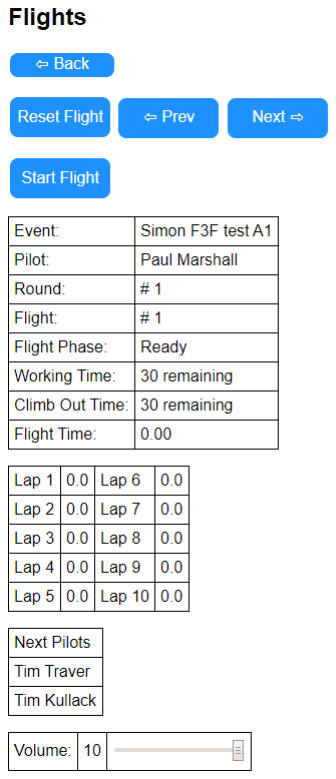
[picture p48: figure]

Saving Rounds to F3XVault

Once one or more flights have been run the flight data can be uploaded to F3XVault from the Rounds page. Select Save Round to Vault. The flight data will then be scored by F3XVault. This is only available for events that have been downloaded from F3XVault.

Downloading Flight Data to Computer

Any event (from F3XVault or manually created) can be downloaded to a computer once rounds have been created. The file provided is in .csv format which can be opened with a text editor or with Excel spreadsheet. The file name will be eventx.csv where x is the event number. The data columns are:

Round, Flight, Pilot, Time, Climb Out, Lap 1, Lap 2 …. Lap 10

- 15 -

Select Download on the Events page for the required event.

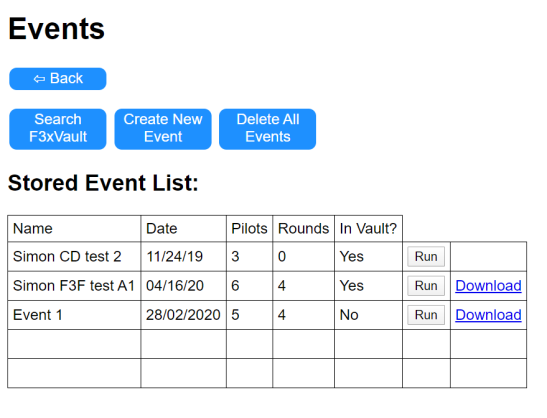
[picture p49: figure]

Clearing the events list

A maximum of five events can be stored on UniTimer. Once that limit is reached all events must be deleted before any new events can be created. There is no single event delete. Select Delete All Events to remove all events from UniTimer. Note that this has no impact on F3XVault.

## 8. Firmware Updates

Updating the firmware is done via a browser. There are two type of files that may need to be updated:

1. Firmware files. The actual code the unit runs. These all have a file extension of .bin, e.g. “F3X UniTimer vx.xx.bin”
2. Support files. The code for the web pages. These typically have a file extension of .mp3, .csv or .html.

Update files will be available from GitHub here:

https://github.com/simonwa2/F3X-Timing-System

Instructions for applying the updates are contained within each version’s page.

- 16 -

## 9. Base Unit Operation

If configured as a base unit, the menus are only slightly different, e.g. no Base Setup option. The unit will automatically go into the correct flight mode once the CD unit goes to an F3F flight start screen.

Signalling a turn can be done in two ways:

1. Pressing the Red button
2. Connecting an external switch to the expansion port (D1)

## 11. Expansion Port

The expansion port provides for the following:

1. Two external switches – e.g. a base turn switch on D1
2. Anemometer (not yet implement in software)
a. Davis 6410, or
b. Peet Bros Ultimeter Pro
3. External alarm/buzzer (not yet implemented in software)

### Connector pins (left to right):

1. Ground
2. 3.3V (for Davis anemometer only)
3. Relay – open collector output for driving a relay for an external buzzer
4. D2 – digital input for anemometer or external switch
5. D1 - digital input for anemometer or external switch
6. A1 – analog input for Davis wind direction

When used as external switches, D1 and D2 have the following functions:

| D1 | D2 | Green button
Event Flights | Pre-launch, Launch then reset | Pre-launch though to Started, then turns | Pre-launch though to Started, then turns
Practice Flights | Pre-launch, Launch then reset | Pre-launch though to Started, then turns | Pre-launch though to Started, then turns
Practice Laps | Start then turns | Start then turns | Start then turns
Base Unit | Sends turn signal to CD | Sends turn signal to CD | Sends turn signal to CD

## 10. Audio Unit Operation

If configured as an audio unit, the menus are only slightly different, e.g. no Base Setup option. The unit will automatically go into the correct flight mode once the CD unit goes to an F3F flight start screen.

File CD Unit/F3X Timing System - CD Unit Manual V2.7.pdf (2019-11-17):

# F3X Timing System – F3F Manual

This manual covers the F3X Timing System in F3F mode using the CD unit.

The system consists of the following units interconnected via a 2.4 GHz radio network:

- CD – manages the F3F event
- Base (or UniTimer) – base turn button with information display
- Audio (or UniTimer) – remote audio for connection to a PA system
- Wind - remote anemometer sends wind speed and direction data to the CD unit
- Display – large LED display panel that shows flight information
- Either:
- Coordinator – network ‘router’ that controls the 2.4GHz radio network (not wifi). Used for systems up to June 2019.
- Repeater – network repeater that improve range. Used for systems from July 2019.

A minimal system comprises one CD, two Base and one Coordinator unit (pre July 2019), or one CD, two Base and one Repeater unit (post July 2019)

# CD Unit Changes in Version 2.7

This update fixes a number of bugs and introduces several new features:

- Manually create and run events off-line
- Correctly handles flight times of 100 secs or longer
- Selectable auto restart times for Practice Flights
- Rotate 2 function for USA round draws
- Prioritises sending turn signals to the audio unit over the bases to minimise latency
- Events correctly download and run if round draw already done in F3XVault
- Wind alerts sent to Audio unit
- Countdown does no over-ride Out Of Course announcement
- Added Delete Round function
- Added capability to mark a pilot as Out of Round or Out of Event

To obtain full functionality at the remote units, updates should also be applied to the Audio and Base units:

- Audio Unit: Version 3.3
- Base Unit:
- Version 2.15 (original small display units up to Nov 2018)

- Version 4.1 (large display units from Dec 2018 onwards)

All updates are available from GitHub:

https://github.com/simonwa2/F3X-Timing-System

GitHub also contains additional instructions and links to videos to help with using the system:

https://github.com/simonwa2/F3X-Timing-System/wiki

# CD Unit

## 1. Description

The CD unit provides the contest director control over an event. Contest data downloaded from f3xvault provides event selection and pilot lists. Flight results can be automatically uploaded to f3xvault for instant results.

The unit connects to other timing system units:

- Base unit – Base A and Base B units
- Audio unit – for connection to a PA system
- Wind unit – provides wind speed and direction to the system
- Display unit – large LED display for providing flight data to competitors and bystanders

The system uses a 4 inch, high intensity, colour touchscreen for operation.

A socket provides direct connectivity to an anemometer or manually connected base buttons if wireless units are not in use. An audio socket is also available to provide direct connect to a PA system. There is also an inbuilt speaker.

Power is provided by two 18650 Li Ion batteries. A CR1220 cell battery maintains the date/time clock when the power is off.

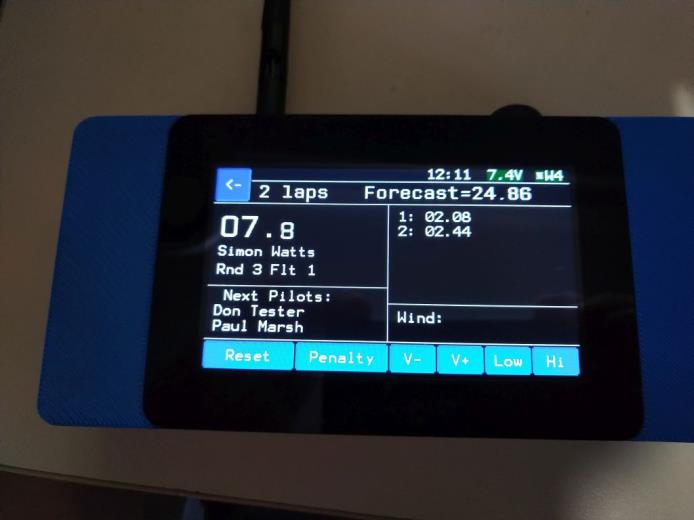
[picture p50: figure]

## 2. Controls

The CD unit primarily uses soft keys on the touch screen.

- Buttons on the bottom of the screen
- A “Back” button on the top left
- Selectable items in lists
- Selectable option items on the screen
- Scrollbars on the left or right of the screen when lists exceed the displayable limit
- Some actions will cause a verification or information panel to popup

### Keyboard

Some actions require entering text, eg names and paswwords. A touchscreen keyboard will popup to allow this data entry.

### Red Button

The red button on the top of the unit is for starting and progressing a flight.

### Information

The top two rows of the screen display information, typically regarding screeen function and activity. Some screen show time, network status, wifi status and battery voltage.

### Voice Announcements

When running a flight the system will make announcements:

- Turn signals
- Lap counts
- Countdowns (pre-launch and launch)

### Network and Wifi Status

Some screens show the local network and wifi connectivity status at the top right of the screen

The status is shown as three symbols, e.g. *W5. This indicates that the local network to the Coordinator is active (the *), the wifi is connected and has signal level 5 (range of 1 to 9). A circle with a diagonal line indicates no connection.

## 3. Startup screen

When initially switched on the unit will go through some system checks and then show the following menu screen:

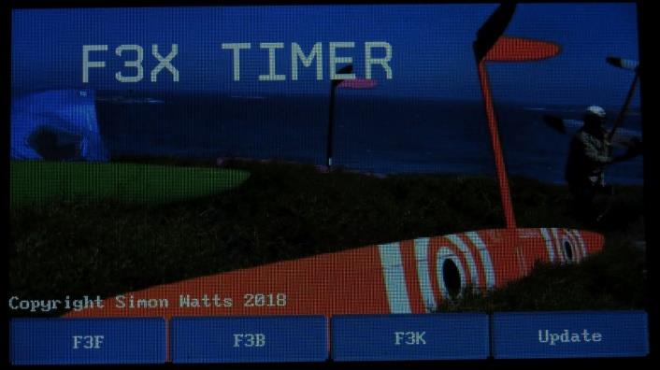
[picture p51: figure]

There are four touch keys:

- F3F - puts the system in F3F mode
- F3B
- F3K
- Update - applies firmware updates to the display module processor

At this time only the F3F and Update buttons operate. Support for F3B and F3K are planned for the future.

## 4. F3F Screen

Selecting F3F from the main menu, sets the system up for managing an F3F event.

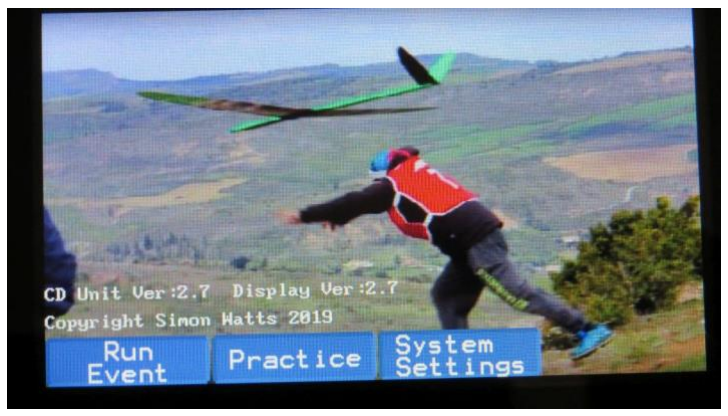
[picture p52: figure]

There are three touch keys:

- Run Event – F3F event selection and running
- Practice – F3F practice mode
- System Settings – configure the system

## 5. Event Selection Screen

This screen shows the currently loaded events, battery voltage and network/wifi connectivity.

There are four touch keys:

- Run Event – Run an event. Takes you to the event rounds and flights
- Look Vault – select and load events from f3xvault
- Add New – manually create a new event
- Manage Event – review event details, save to F3xVault, delete event or add pilots to the event
- Manage Pilots – not yet implemented. This option will allow you to save pilot names to a local database and use the list to when manually creating new events without F3xVault.

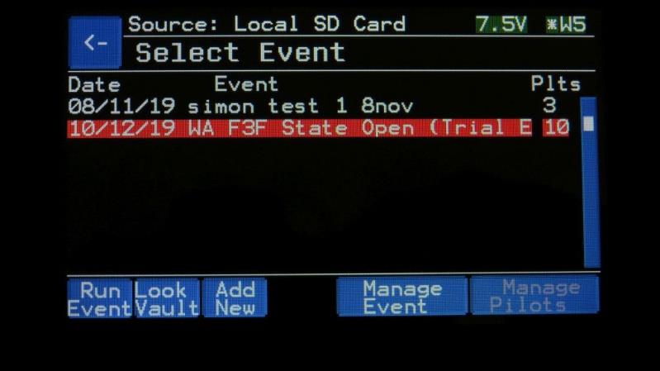
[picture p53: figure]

## 6. F3xVault

Events created in f3xvault as F3F Slope Race (Plus Scoring) can be downloaded to the CD unit. Selecting Vault from the Contests screen will trigger connection to f3xvault and provide a list of available contests. A contest can be selected and then loaded into the CD unit internal storage.

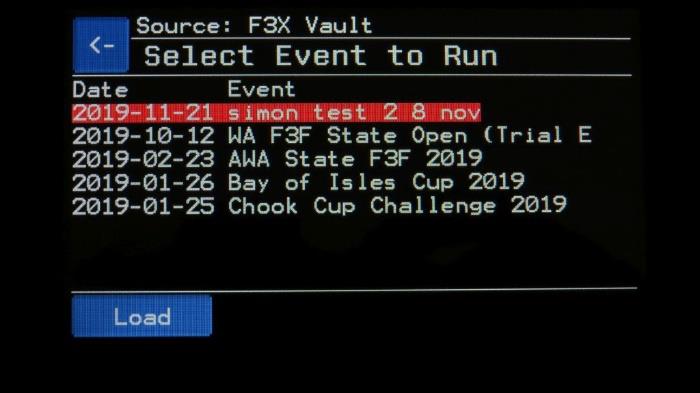
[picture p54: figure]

The “Load” key loads the slected event into internal storage and returns to the main event selection screen.

If rounds or results for an event already exist in f3xvault, then there is an option to download the rounds/results. This allows you to create and event and do the rounds draw in F3xVault if you wish.

## 7. Manage Event Screen

Shows details of the event and the pilot list. When first opened it will show various event data:

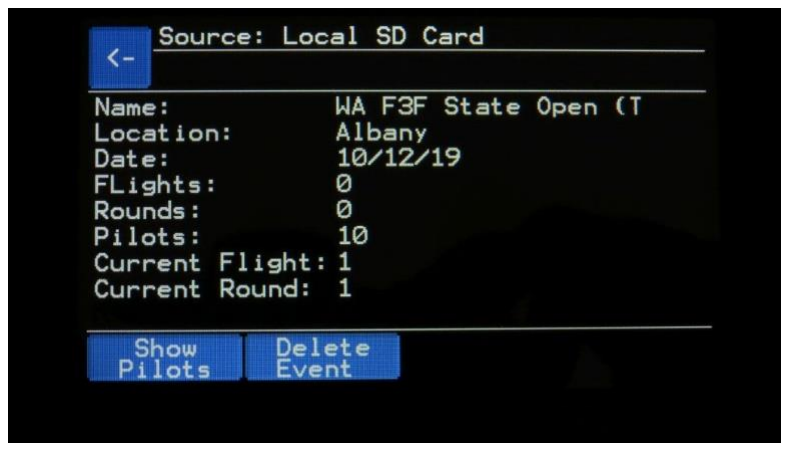
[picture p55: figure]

Options on this screen are:

- Show Pilots – switches the content to show the event pilots
- Delete Event – remove the event from the CD Unit. This will not remove it from F3xVault.
- Save in Vault – an event that has been manually created must be saved to the Vault before any flight results can be uploaded to the Vault. Saving can be done after the event has been run. This option only shows if the event has not yet been saved.

Selecting “Show Pilots” will switch the screen to show the pilot list.

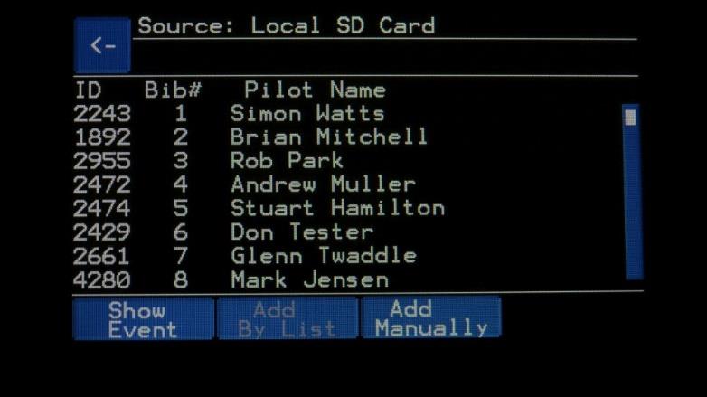
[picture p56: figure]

Data displayed will be:

- ID – this is the pilot’s ID in F3XVault
- Bib# - a number derived from the entry order (not the flight order)
- Pilot name

Options on this screen are:

- Show Event – switches the content to show the event pilots
- Add By List – not yet implemented, this will allow you to add pilots from a locally saved list.
- Add Manually – add a pilot by entering their name and country
- Save in Vault – save pilots to the event in F3XVault. Required before flight results can be uploaded to F3XVault. Saving can be done after the event has been run. This option only shows if a pilot has not yet been saved.

## 8. Rounds Screen

The Rounds screen shows the list of rounds and the flight order/results for the selected round

There are six touch keys:

- Run – run the selected round and flight (highlighted in red)
- New Rnd – generate a new round of flights
- Delete Rnd – delete the selected round and all subsequent rounds
- Edit Pilot – change the status of a pilot – In Round, Out of Round, or Out of Event
- Save Rnd – save all flights the selected round to f3xvault, that have not already been saved
- Save All – save all flights in the contest to f3xvault, that have not already been saved
- -Pen – remove a penalty from the selected flight
- +Pen – add a penalty to the selected flight

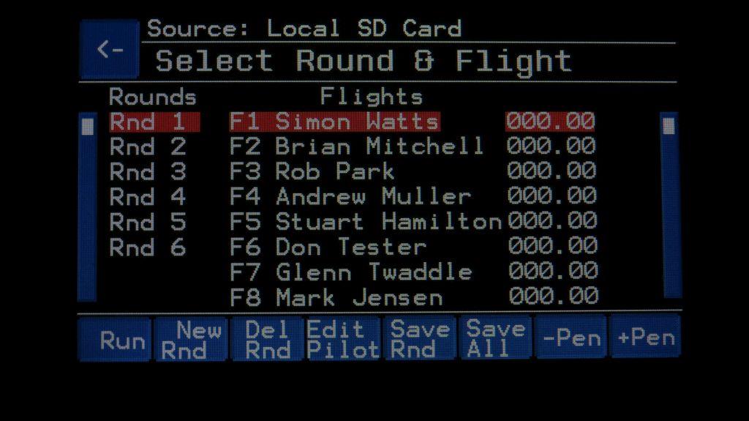
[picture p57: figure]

The Rounds screen shows the status of flights that have been run:

- Flight time
- Penalty (P)
- Saved to f3xvault (S) or run but not saved (R)

If the status of a pilot has been changed then it will be displayed:

- Out of Round: Greyed out
- Out of Event: Greyed out with a line through the name and time

Pilots that are marked as out of round or out of event will be skipped in the flight order as the event progresses.

## 9. Generate Round screen

The Generate screen will create a new round. There are three keys:

- Generate – creates a round with the selected flight order
- Rotate 2 – rotates the flight order by two. This has been used in the US to assistance in manning the bases
- Random – generates a random flight order

- Edit Pilot – change the status of a pilot – In Round, Out of Round, or Out of Event

Marking a pilot Out of Round or Out of Event will place them at the bottom of the flight order when the round is generated. Their status can be changed after generating the round.

The flight order can also be manipulated manually. The selected pilot can be moved up or down in the flight order using the UP and DN buttons.

The number of rounds to generate can be selected from 1 to 6. Touching the “Round to Gen” text will rotate through the number of rounds to generate.

In Western Australia, we usually run back to back flights. A pilot flies two rounds without landing between the first and second. This reduces time spent launching and landing, resulting in more rounds flown. The number of back to back rounds is selectable between 1 and 6.

Some USA events rotate the flight order by two pilots each round. This helps with rostering pilots to also be button pressers on bases for small events. Selecting “Use Rotate 2” will automatically rotate the flight order when multiple rounds are generated. Using the “Rotate 2” button will just rotate the on-screen flight order.

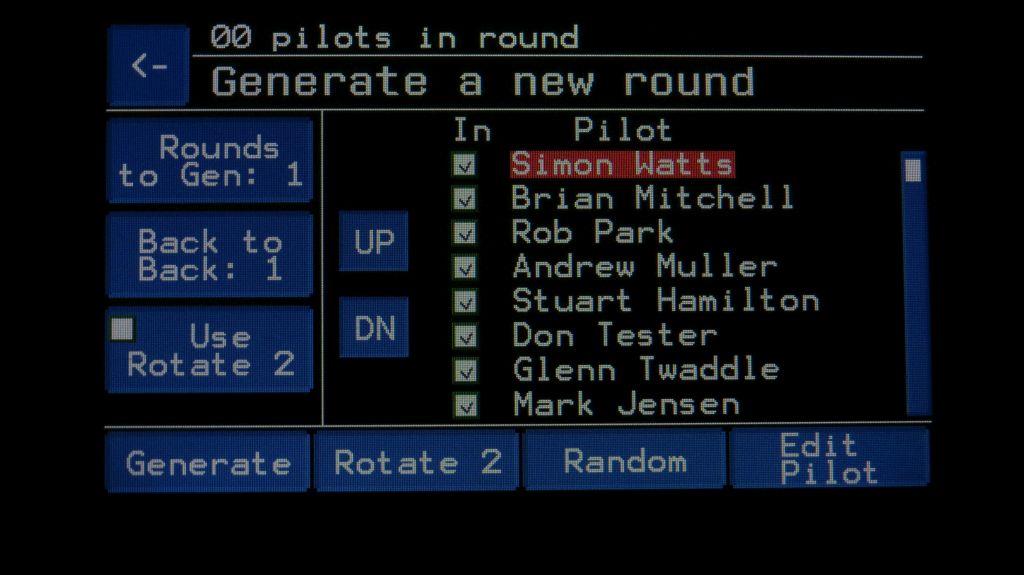
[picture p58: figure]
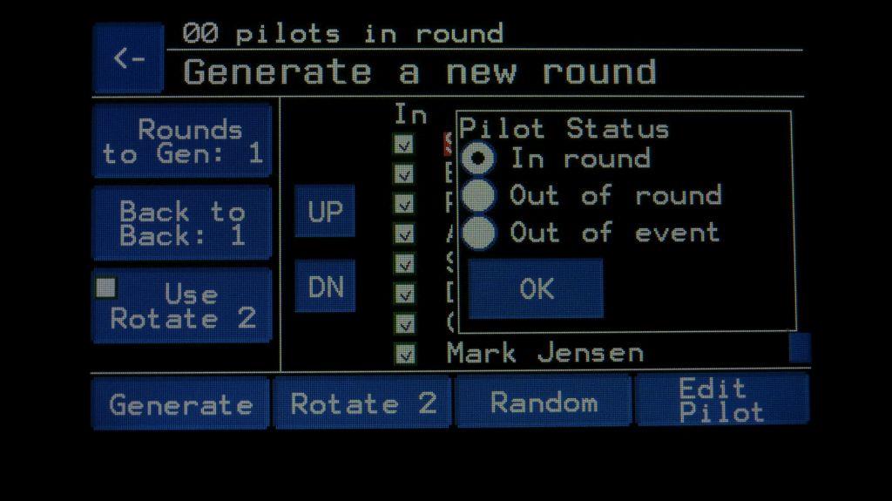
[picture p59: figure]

## 10. Flight Screen

The flight screen shows the currently running flight. Information provided includes:

- Flight time
- Flight state: Ready, Pre-Launch, Launched, Out, Started, Finished
- Lap count
- Round and Flight numbers
- The names of the next two pilots to fly
- Lap times
- Wind state – speed and direction

The touch keys change depending on the flight state. When a flight is running the keys are:

- Reset – reset the flight. To prevent accidental reset, a confirmation popup appears.
- Penalty – apply a 100 point penalty. To prevent accidentally applying penalty, a confirmation popup appears.
- V- & V+ - volume control for the inbuilt audio
- Low & High – change the screen intensity between low, medium and high settings. Normally Low should be used. High may be useful in full sun.

Note that the “Back” button (top left of screen” will only work when a flight is in the Ready state. This prevents accidentally exiting a running flight.

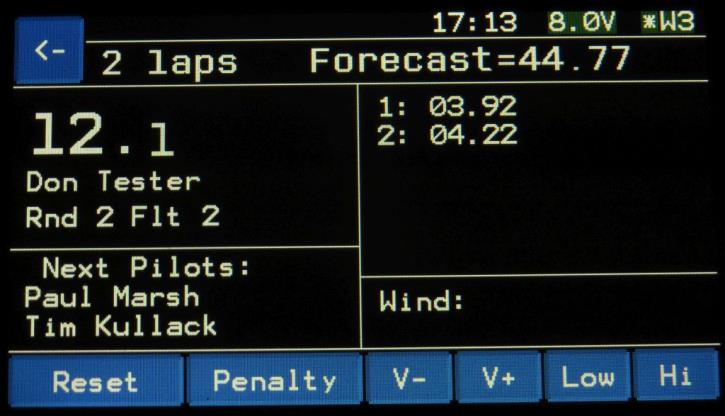
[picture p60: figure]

In the flight Ready state the keys change. Reset and Penalty are replaced by << and >>. These keys allow the CD to move through the flight order. Useful if a flight has to be skipped.

The signal strength of connected units is also shown as a range of 1-9 (9 is high). An X indicates that the unit should be connected, but is not responding – probably turned off or out of range.

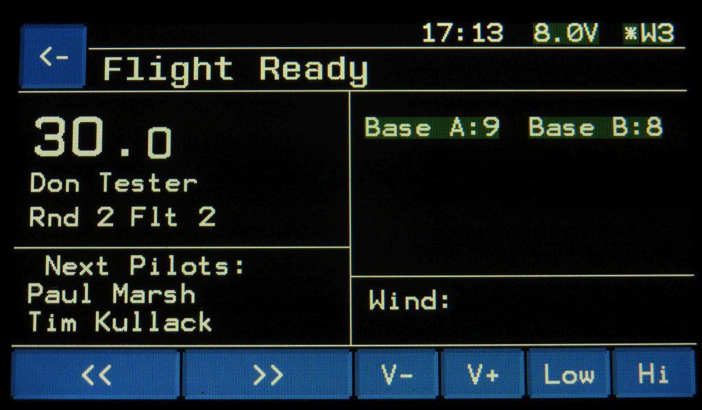
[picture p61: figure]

## 11. System Settings

Consists of a number of screens to configure external units, wifi and f3xvault connectivity.

At the System Settings screen there are five touch keys at the bottom of the screen:

- Setup F3XVault – opens a second setup screen for setting up F3XVault connectivity
- Setup Wifi
- Audio Settings
- Disp – change the screen intensity
- Diag – show the diagnostics screen

There are three touch areas on the screen for anemometer setup:

- Wind Internal/External – Internal Davis or Internal Peet if an anemometer is plugged directly into the CD unit. External if a Wind Unit is used.
- Units – selectable as m/s, kph, knots, or mph
- Ave over – selectable time to average the readings shown on the display (1 to 10 seconds)

External Units. Selecting a base or other unit links the CD unit to the selected device. A tick shows that a link has been established. Wifi can also be enabled/disabled on this screen.

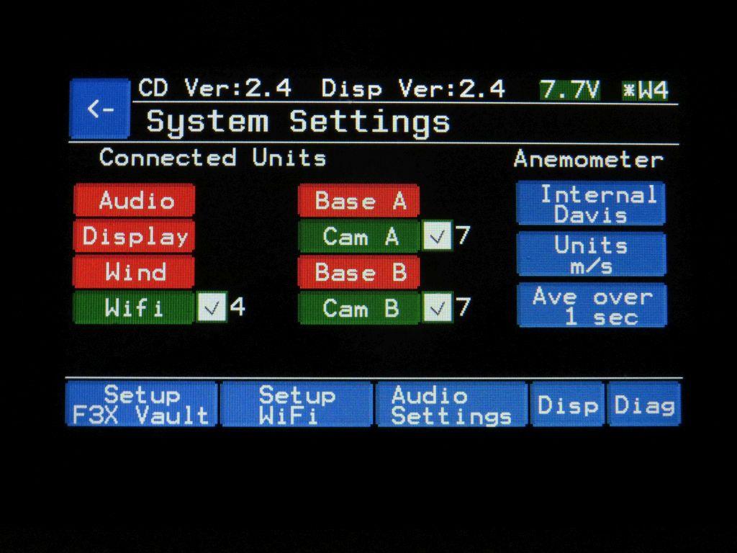
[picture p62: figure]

## 12. F3X Vault Setup

On the Vault screen there are two buttons at the bottom:

- Test Login – checks that the system can connect to F3XVault with the users credentials
- Clear Event (with double confirmation) – clears all saved contests from the system. It does not affect any events in f3xvault

There are also seven touch areas on the screen:

- Vault Username and Password. Shows the current user in F3xVault. Touching it allows the user and password to be set. Must be set for access to load and save event data to F3xVault.

- Search Country – code to be used when retrieving events from F3XVault, e.g. au for Australia, us for USA, fr for France, etc.
- Flight Save – selectable between;
- Each Flight – auto saves at the end of every flight
- Manual – manually initiate saving from the Rounds screen for a round or the whole event
- Search forward – number of months (0 to 12) to search forward in time when looking for events in f3xvault
- Search backward – number of months (0 to 12) to search backward in time when looking for events in f3xvault

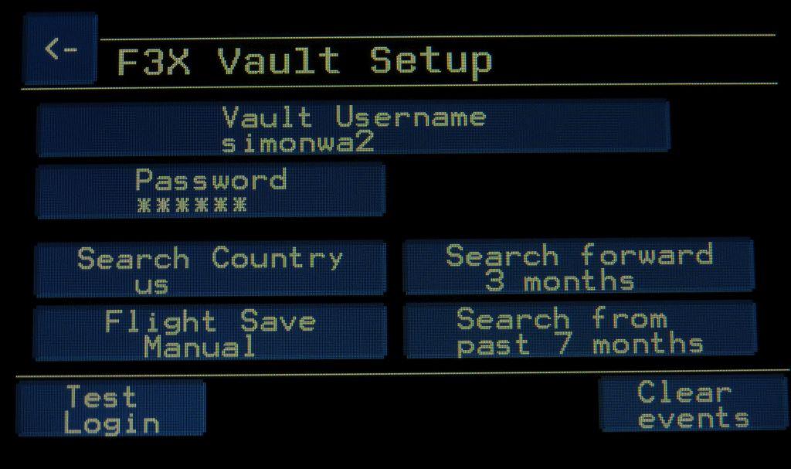
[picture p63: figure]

## 13. Wifi Setup

Sets the wifi SSID that the CD unit will connect to. This must be set manually, the CD unit will auto-connect to any available wifi routers.

There are four keys at the bottom:

- Scan – initiate a scan of available wifi routers
- Test Login – test that the router login works
- Forget SSID – removes the router ssid from the system
- Set Time – sets the system date and time

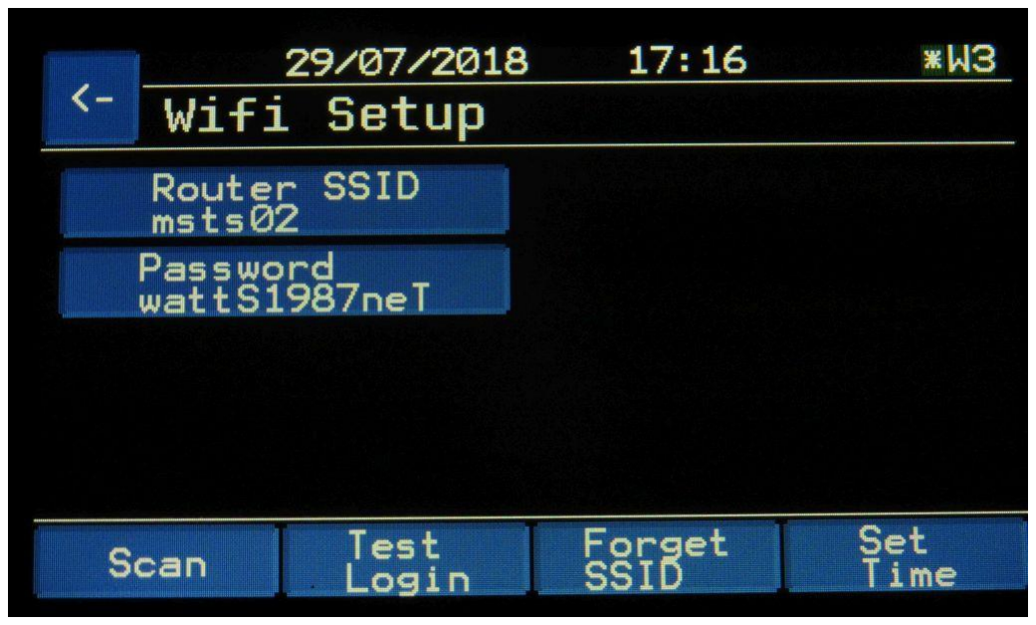
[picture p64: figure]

When a scan is run the system will display all currently available routers and their signal strength (RSSI). Selecting a router from the list and pressing “Select” will connect the system to that router. If it has previously been connected to, the system will apply the saved password. If it is a new router then the password will be requested.

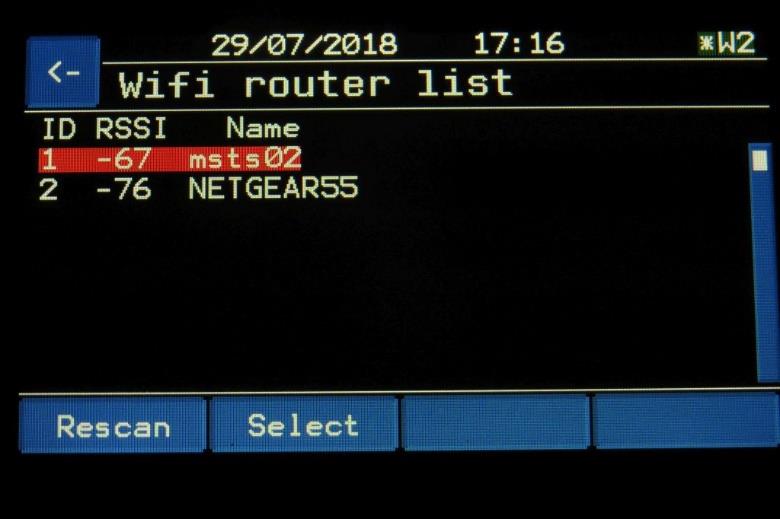
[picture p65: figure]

## 14. Audio Setup

Set the turn beeps and time based audio clips.

### Turn Beeps

Select the beep to play for:

- Turn – played for all turns
- 2

nd Turn – played only in practice mode is double beep turned on
- Ready – played when moving to the next pilot

### Time Clips

Set a clip to play and a flight time threshold to play it at.

- Two clips each with a different threshold
- Change the threshold time between 20 and 60 seconds

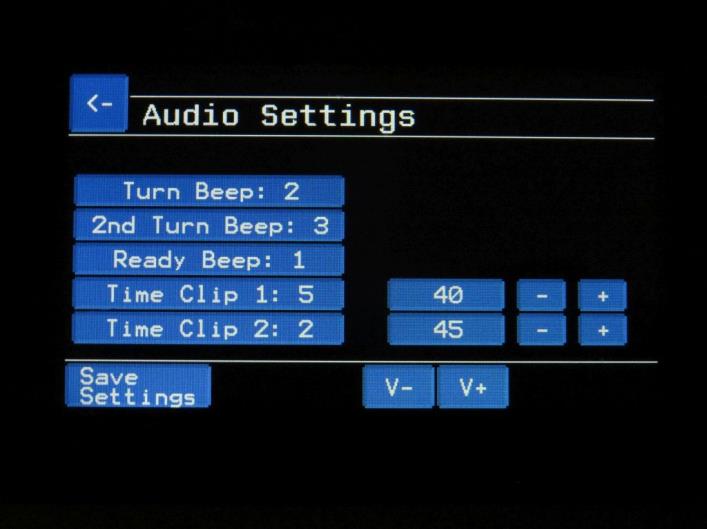
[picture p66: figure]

## 15. Diagnostics

The diagnostic screen provides some information regarding the connectivity to external devices, i.e. base units or camera units.

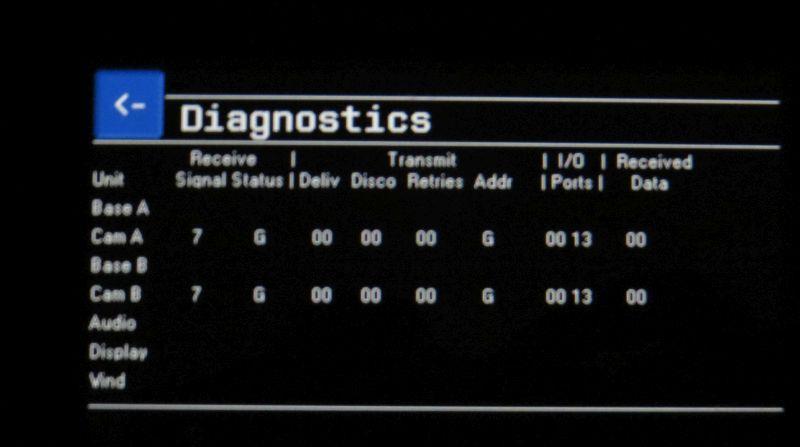
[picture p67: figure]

In this mode the CD unit will emit a beep if any external unit sends a turn signal.

## 16. F3F Practice

There are two practice modes:

- Flight – continuous full flights with flight time announcement. Manual or automatic restart.
- Laps – continuous laps with time announcements.

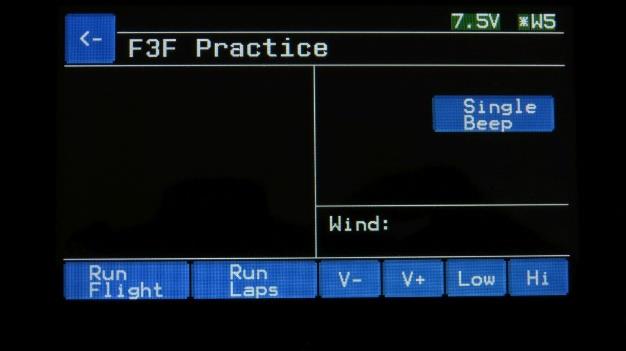
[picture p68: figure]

The practice modes can be set for:

- Single beep – only the normal turn (out) signal is given
- Double beep – the back onto course signal is also given

The practice flight mode has an automatic restart option. It can be set to:
- Auto Off – at the end of the flight, the system will stop until the Red button is pressed
- Auto 10s, 15s, 20s, 25s, or 30s – at the end of the flight the system will automatically start a new flight after the selected duration.

### Practice Flight

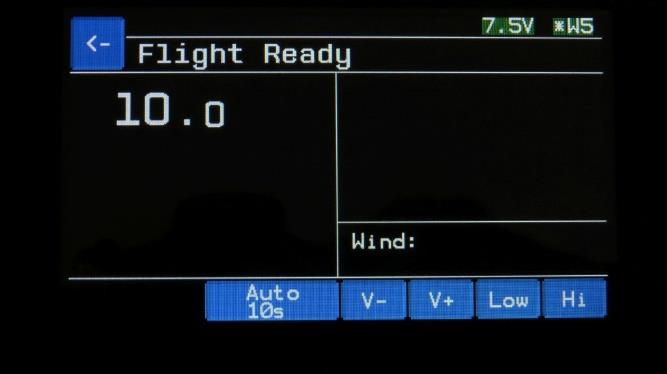
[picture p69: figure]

### Practice Laps

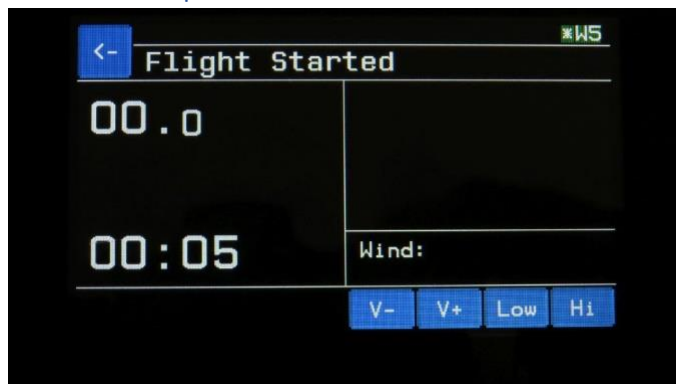
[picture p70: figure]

# Setting Up the System

The following describes the initial system setup.

### Wifi

- Set wifi router name and password in Wifi Setup screen
- Set system date and time
- Ensure WiFi is selected on (Green and ticked) in System Settings screen

### F3XVault User

- Set the Vault User and password to match that used to create the contest in F3xVault
- Set Search Country, Flight Save and Search Forward/Backward options

### Anenometer

- Set to Internal Davis, Internal Peet or External. If not using an anemometer the set to External.
- Select units to display
- Select time to average readings over

### Bases and Other Units

For each external unit that is to be connected:

- Make sure external unit is switched on and connected to the network (Coordinator Unit must be on for pre-July 2019 CD units)
- Select the unit on the Setup screen. Colour should change to Green (unit is connected) and tick box should be ticked (unit has been linked). The signal strength is also shown.

Note that it may take up to 30 seconds for a unit to connect to the network when first switched on. Selection will not be successful until the unit is connected to the network.

### F3X Vault Event

To set up an event from F3XVault:

- Create the event (with pilots) in F3xVault. It must be created with the type set to “F3F Slope Race (Plus Scoring)”.
- Add the contest to the CD unit:
- Select Vault from the main screen and then OK. Available contents will then be listed
- Select the required contest and select Load. Contest is downloaded and stored. System returns to the main Contests screen
- Create some rounds to fly
- Select the event to run from the main Events screen
- Select Run from the main screen and then OK.
- Select New Round and then OK
- Set the flight order (defaults to order pilots were added to f3xvault):
- Manually select a pilot and use the UP or DN buttons to move in the flight order
- Select Random to generate a random flight order

- Select Rotate 2 to move the pilots up the list by two positions
- Select Generate and then OK

### Run the event

From the rounds screen select the round and flight to run – usually Round 1, Flight 1.

Check correct pilot name shown on Flight screen. Press the red button on the top of the unit to start the flight. A flight goes through several states:

- Flight Ready – ready to start. Pressing the red button on the top of the unit starts the flight
- Pre-Launch – 30 second countdown for the plane to be launched
- Launched – 30 seconds countdown to enter the course
- Out of Course
- Flight Started
- Laps
- Lap count
- Lap times
- Forecast
- Flight Finished
- Time announced
- Flt saved to SD
- Flt saved to Vault (if Save Each Flight has been selected)

At the end of a flight, pressing the red button will advance to the next flight and pressing it again will start the flight. You can also use the left and right arrows to skip pilots if necessary, e.g. pilot not ready in time.

### Manually Created Event

To manually create and set up an event without using F3XVault:

- From the Events screen, select Add New and then OK
- Enter the following as prompted on screen:
- Event name
- Location
- Date – note format is MM/DD/YYYY
- Select the event once it is created and select Manage Event
- Add pilots to the event:
- Select Show Pilots
- Select Add Manually
- Enter pilot details:
- First name
- Last name
- Country code – e.g. au for Australia
- Repeat for each pilot

At this point the event can be run, but results cannot be saved to F3XVault.

To enable saving of results to F3XVault:

- Save the event to the Vault:
- Select Manage event
- Select Save in Vault
- Save the pilots to the event in the Vault:
- Select Manage the event
- Select Show Pilots
- Select Save in Vault
•

Note that when saving the pilots to the Vault, the system will attempt to match the pilot name to a Vault entry. If it finds a match then it will use that pilot. If it cannot match then it will create a new pilot in F3XVault. Matching is based on the spelling of the name. So it is important to spell the name correctly.

### Saving Flights to F3XVault

During running an event, flight data can be uploaded automatically or manually and includes:

- Time of flight
- Flight time
- Penalties
- Average wind speed and direction
- Lap times and time from launch to entering the course

Results are available from f3xvault during the contest as they are uploaded.

The selected setting in System Settings - F3XVault controls how the upload is run:

- Flight Save Manual – flights must be saved to F3XVault manually from the Rounds screen. The save can be initiated at any time, e.g. after each round, or after the event is finished.
- Flight Save Each flight – the system will attempt to save the flight data at eh end of each flight. This requires an active wifi connection to the Internet during the event.

# Updating the System

The CD unit uses a Teensy 3.2 microcontroller which supports code written for the Aurduino platform. There is also a dedicated processor in the display. Both processors must be updated, however the method is different for each.

- Teensy 3.2 Processor – always updated via USB
- Display processor – updates via SD card

There are two USB ports:

- Teensy 3.2 processor. Located at the top of the unit
- Display Processor. Located at the bottom of the unit

There are two micro SD cards:

- Display SD – contains fonts and graphics. Also used for display processor updates. It is only accessible with the case open
- Teensy SD – contains sound files and event data. It is accessible from a slot in the top of the unit. All flight data is written to this card.

The unit should be left turned off whilst programming. The unit will power up from either USB port. Only use one port at a time. The two ports’ power lines are tied together.

Updates are available from GitHub:

https://github.com/simonwa2/F3X-Timing-System

## 1. Update Folder

The CDVxx folder contains the following folders:

- Display SD Card Update – graphics and firmware to be loaded on the display’s micros sd card.
- Teensy SD Card Update – has two folders
- Audio – mp3 audio files
- Contests – event data. Must be empty for this release
- Teensy Update – firmware to update the Teensy processor

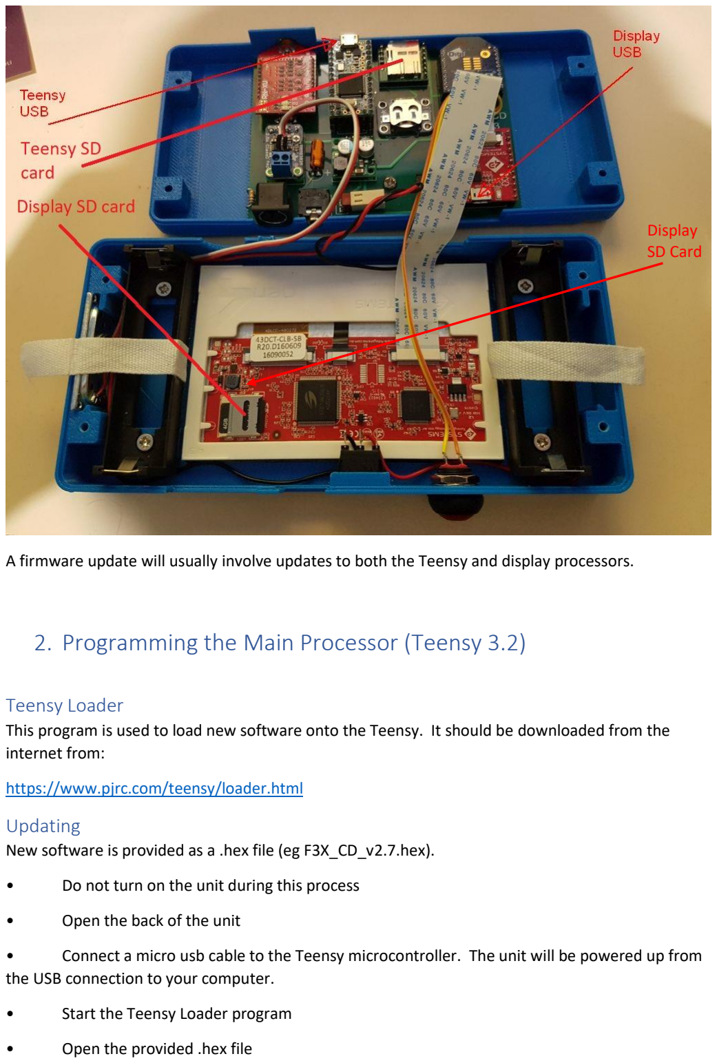
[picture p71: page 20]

A firmware update will usually involve updates to both the Teensy and display processors.

## 2. Programming the Main Processor (Teensy 3.2)

### Teensy Loader

This program is used to load new software onto the Teensy. It should be downloaded from the internet from:

https://www.pjrc.com/teensy/loader.html

### Updating

New software is provided as a .hex file (eg F3X_CD_v2.7.hex).

- Do not turn on the unit during this process
- Open the back of the unit
- Connect a micro usb cable to the Teensy microcontroller. The unit will be powered up from the USB connection to your computer.
- Start the Teensy Loader program
- Open the provided .hex file

Display
SD Card

- Select "Auto" on the Loader
- Press the reset button on the Teensy microcontroller (see photo)
- After a few seconds the Loader program will show "Programming" and then "Reboot OK"
- The Teensy processor will restart and the program update is complete.
- You will have to restart the system for the update to be seen.

### Teensy Micro SD Card Update

The Teensy sd card is updated by copying the Audio and Contests folders to the sd card, overwriting the existing content.

## 3. Programming the Display Processor (Diablo)

### Display Micro SD Card Update

The display sd card contains both graphics and program code that must be updated.

To apply the update:

- remove the display sd card from the display unit. The card holder is opened by sliding the latch and opening it upwards.
- copy the contents of the “Display SD Card Update” folder to the sd card, replacing the existing files.
- replace the sd card in the display and latch it closed
- power up the CD unit and select “Update” from the main menu.
- Select OK when prompted to update the firmware:

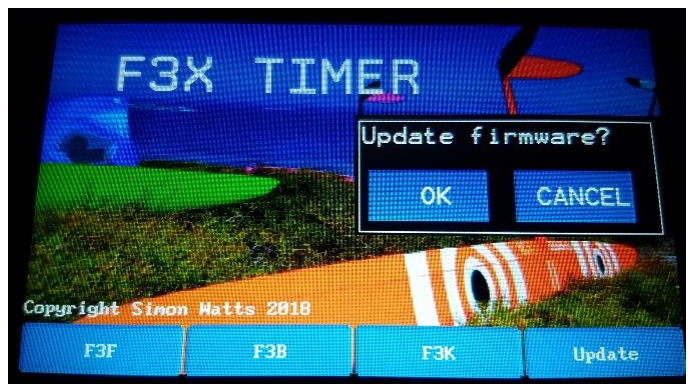
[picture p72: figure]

- The following should be shown on the display as the system updates. It will then return the main start-up screen and be ready for use.

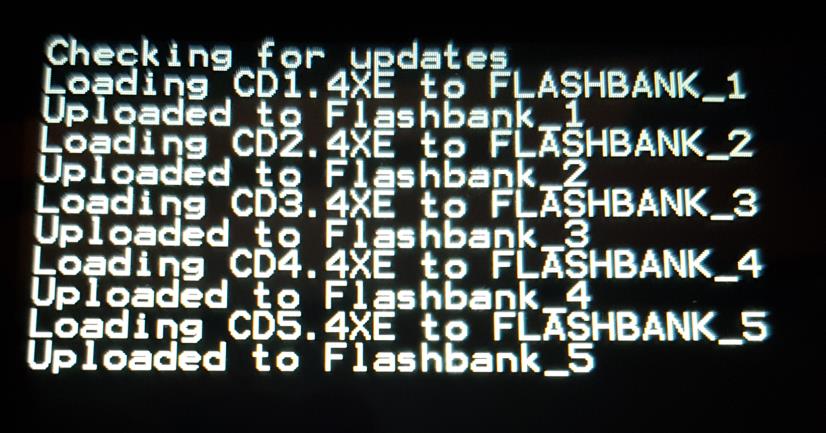
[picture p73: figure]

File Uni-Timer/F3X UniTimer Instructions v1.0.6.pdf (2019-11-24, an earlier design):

- 1 -

# F3X Uni-Timer Version 1.0.6

## Contents

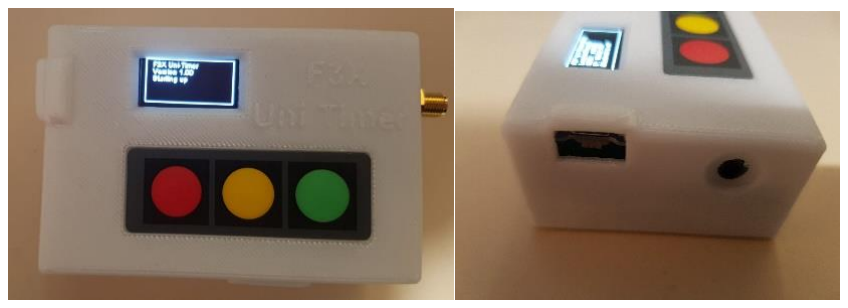
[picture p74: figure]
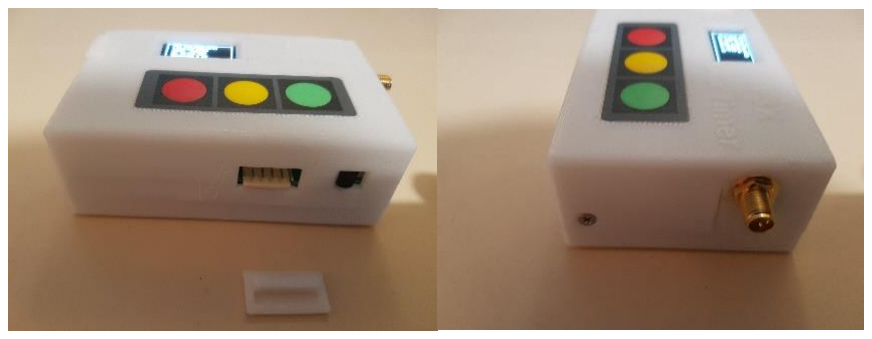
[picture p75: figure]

- 2 -

## 1. Introduction

Version 1 of the Uni-Timer is an early development of the full potential of the unit. Some functionality has not yet been implemented. Web pages are very simplistic. Bluetooth is very experimental and subject to failure. However, the unit does operate as either a central timing unit or as a base unit.

## 2. Switches and ports

1. Display
2. Menu and operation switches
3. USB port – connect to phone charger to charge the battery
4. Audio out – connect headphones or a powered speaker
5. Expansion port
6. On/off switch
7. Antenna
8. Case screw
9. Charging LED

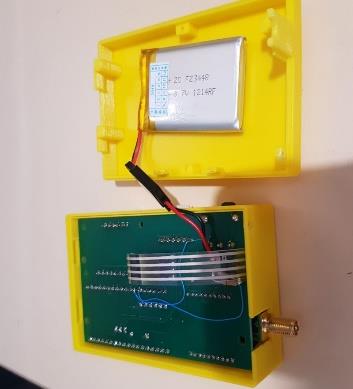
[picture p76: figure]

- 3 -

## 3. Battery

The system is designed to be powered by a single cell (1S, 3.7V) LiPo or LiIon battery. A flat 1,200 mAh or 2,000 mAh battery will fit. The unit has been fitted with a female JR style 3 pin connector.

### Installation

The case must be opened to install the battery. Remove the case screw and antenna nut. The case can then be hinged open from the antenna end. The battery can then be mounted to the case back using double sided tape.

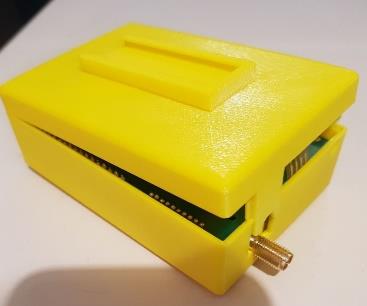
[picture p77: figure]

### Charging

The unit has a USB charger built in. Connecting a USB power source and turning the unit on will initiate charging. Charge time is approximately 8 hours for a 1,200 mAh battery. Charging is indicated by a red LED visible through the case to the left of the display (not for dark blue cases). The LED has three modes when the USB is connected:

1. Flashing – USB power has been applied, but power switch is off – unit is not charging
2. Solid red – unit is charging
3. Off – battery is fully charged

Note that the unit can be used whilst charging. It will turn on as soon as USB power is connected.

Units made from July 2019 also have a charge socket next to the antenna connector. This is a three-pin header that a standard JR connector will plug into. The centre pin is positive and the two outer pins are negative. The header is directly connected to the battery so a standard LiPo charger can be used. The charging rate should be kept down to about 500 mA for these small batteries.

### Battery voltage indicator

The battery voltage is visible on the main menu and the flight screens.

- 4 -

## 4. Starting

When powered on, either by battery or USB, the unit will go through start-up stages dependent on its settings:

1. Power on screen
a. Startup
b. Wifi initialisation (if wifi enabled)
c. Bluetooth initialisation (if Bluetooth enabled)
2. Information screen – shows web server URL, wifi mode, Bluetooth status
3. Pressing the yellow button then shows the main menu


## 5. Navigation

There are three buttons used to navigate the system:

1. Red – flight reset
2. Yellow – menu item select
3. Green – menu item navigation and flight start

## 4. System Menus

### Main Menu

The main menu has the following (in Base Unit configuration the Setup Bases item is not present):

1. F3F Flights – flight menus
2. Setup Bases – base and camera unit selection
3. Options – setup options
4. Sleep – puts the unit into low power sleep mode. Use when charging.
5. Network Info – displays network connection information

### F3F Flights Menu

1. Practice Flights
2. Practice Laps
3. Contest Flights (not yet implemented)

### Options Menu

1. Volume – Cycles through 10 steps by pressing Yellow button
2. Unit Type – CD, Base A, Base B, Audio, or Wind (changing requires a restart)
3. Wifi – Client, AP, or Off (selecting goes to the wifi menu)
4. SSID – ID of the wifi to connect to (selectable from a stored list of five)
5. Bluetooth – On or Off (selecting goes to the Bluetooth menu)

- 5 -

### Bases Menu

Allows binding of base or camera units to use with the system.

Binding process

1. Ensure that the relevant base or camera unit is turned on
2. Select the unit in the Base menu. It will show ‘On’ and should also show ‘Linked’ to confirm that binding has been successful and then the signal strength (1-10).
3. This process only needs to be done once. The configuration is saved and subsequent use of the system uses the saved configuration.
4. Units should be deselected if they are not being used (‘-‘ shown next to unit name)

### Wifi Menu

The WiFi type can be selected to be one of:

- Client (UniTimer connects to an access point, e.g. a mobile phone hotspot)
- AP (UniTimer sets up its own access point)
- Off (Wifi is turned off)

A restart is necessary when switching Wifi modes

### Bluetooth Menu

The affects only the Bluetooth button operation. It has no effect on Bluetooth audio, which is always enabled (if fitted).

Bluetooth can be set to:

- On, or
- Off

The button type must be set. It is selectable between:

- iTAG button
- TrackerPA button

A restart is necessary when switching Bluetooth modes

### Signal indicator

A small Y or N will show in the bottom right of the display on the flights pages and setup menu.
When using the unit as a base unit, this indicates connection to the central timing unit. Y=connected. N=not connected.

- 6 -

## 5. Wifi

### Wifi Modes

The unit has three wifi modes:

1. Client Mode – connects to a wifi access point, e.g. a router or phone set to be a mobile hotspot
2. AP Mode – runs its own access point that other devices can connect to
3. Off – wifi disabled

When in Client or AP mode, devices such as smart phones can connect to the unit’s web pages for information and configuration.

### AP Mode

If AP mode is selected then the unit will start up its own access point called ‘F3X Timer’. To use this:

1. Use a wifi device, e.g. mobile phone to connect to the unit
2. On the phone wifi setup select ‘F3X Timer’ from the available wifi sources
3. In a web browser, enter 192.168.1.4 as the address to use

AP mode must be used for setting up the client mode access point details.

### Client Mode

If Client mode is selected, then the unit will attempt to connect to a local wifi access point using saved credentials. These credentials are stored in a file on the system called ssids.csv. The details (SSID name and password) of up to five access points can be stored in the system. The access point to use is selected in the Options menu.

If the access point is not turned on, not in range, or the credentials have not been set, then a warning will show saying that it is unable to connect. Press the green button to continue. Wifi will not be active.

Further details on setting up Wifi are available here:

https://github.com/simonwa2/F3X-Timing-System/wiki/F3X-Uni-Timer---wifi-modes

and:

https://github.com/simonwa2/F3X-Timing-System/wiki/F3X-Uni-Timer---configuring-for-multiple-wifi-access-points (https://github.com/simonwa2/F3X-Timing-System/wiki/F3X-Uni-Timer---configuring-for-multiple-wifi-access-points)

## 7. Bluetooth

Bluetooth can be used to connect a remote button (iTag or TrackerPA). The button is used to start/reset a flight (unit as CD) or signal a turn call (unit as a base).

The button type should be selected from the Bluetooth menu.

The button device should be turned on prior to turning on the unit with Bluetooth enabled. The system will try to connect for about 15 seconds. If that fails it will ignore Bluetooth.

This function is experimental and subject to connection failure.

- 7 -

## 8. Web Pages

The unit has a web server that provides web pages for controlling and viewing flights, and for configuring the system. The address to use is shown on the startup screen.

The web pages are in an early stage of development and are not fully functional, but the information shown on the pages is correct.

### Main page


### System Settings

Shows the current configuration for the bases and wifi. The wifi access points to use are set on this page


- 8 -

### Practice Flight

Lap times and Total flight time are shown as the flight progresses


- 9 -

## 9. Firmware Updates

Updating the firmware is done via a browser. There are two type of files that may need to be updated:

1. Firmware files. The actual code the unit runs. These all have a file extension of .bin, e.g. “F3X UniTimer vx.xx.bin”
2. Support files. The code for the web pages. These typically have a file extension of .mp3, .csv or .html.

Update files will be available from GitHub here:

https://github.com/simonwa2/F3X-Timing-System

Instructions for applying the updates are contained within each version’s page.

- 10 -

## 10. Base Unit Operation

If configured as a base unit, the menus are only slightly different, e.g. no Base Setup option. The unit will automatically go into the correct flight mode once the CD unit goes to an F3F flight start screen.

Signalling a turn can be done in three ways:

1. Pressing the Red button
2. Using a Bluetooth button
3. Connecting an external switch to the expansion port (D1)

## 11. Expansion Port

The expansion port provides for the following:

1. Two external switches – e.g. a base turn switch on D1
2. Anemometer (not yet implement in software)
a. Davis 6410, or
b. Peet Bros Ultimeter Pro
3. External alarm/buzzer (not yet implemented in software)

### Connector pins (left to right):

1. Ground
2. 3.3V (for Davis anemometer only)
3. Relay – open collector output for driving a relay for an external buzzer
4. D2 – digital input for anemometer
5. D1 - digital input for anemometer or external switch
6. A1 – analog input for Davis wind direction

- 11 -

## 12. F3F flights

### Practice Flights

Practice Flights provide full timing but are not saved to storage (currently). The sequence for a flight is the following stages:

1. Ready. Press Green button (or Bluetooth iTag) to start.
2. Pre-Launch. 30 second pre-launch countdown. Press Green button (or Bluetooth iTag) to launch.
3. Launched. 30 second climb-out countdown.
4. Out of Course. When signal received from base A, or Green button pressed
5. Started. When entered the course as signalled by Base A or Green button pressed
6. Lap counts
7. Finished

To reset a flight, press the Red button at any point of the flight, or the iTag once the flight is at Launched stage or later.

Manual or automatic start of the next flight can be set on the F3F Flights menu. The options are 10s, 15s, 20s, 30s or manual start. If an auto start time is selected then, at the end of a flight, a pre-launch countdown will commence. This gives the pilot time to fly back to the centre of the course n time to get the Launched signal and commence the 30s climb-out to start the flight,

To return to the Flights menu, press the Yellow button in the flight Ready stage.

### Practice Laps

Practice laps provides for continuous laps, with the individual lap time called out. This allows testing of different turn techniques. Press Green button to start. Red button to Reset.

### Contest Flights

Currently this is not implemented. It will provide for full contest timing.

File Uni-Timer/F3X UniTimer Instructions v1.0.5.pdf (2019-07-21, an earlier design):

- 1 -

# F3X Uni-Timer Version 1.0.5

## Contents


- 2 -

## 1. Introduction

Version 1 of the Uni-Timer is an early development of the full potential of the unit. Some functionality has not yet been implemented. Web pages are very simplistic. Bluetooth is very experimental and subject to failure. However, the unit does operate as either a central timing unit or as a base unit.

## 2. Switches and ports

1. Display
2. Menu and operation switches
3. USB port – connect to phone charger to charge the battery
4. Audio out – connect headphones or a powered speaker
5. Expansion port
6. On/off switch
7. Antenna
8. Case screw
9. Charging LED


- 3 -

## 3. Battery

The system is designed to be powered by a single cell (1S, 3.7V) LiPo or LiIon battery. A flat 1,200 mAh or 2,000 mAh battery will fit. The unit has been fitted with a female JR style 3 pin connector.

### Installation

The case must be opened to install the battery. Remove the case screw and antenna nut. The case can then be hinged open from the antenna end. The battery can then be mounted to the case back using double sided tape.


### Charging

The unit has a USB charger built in. Connecting a USB power source and turning the unit on will initiate charging. Charge time is approximately 8 hours for a 1,200 mAh battery. Charging is indicated by a red LED visible through the case to the left of the display (not for dark blue cases). The LED has three modes when the USB is connected:

1. Flashing – USB power has been applied, but power switch is off – unit is not charging
2. Solid red – unit is charging
3. Off – battery is fully charged

Note that the unit can be used whilst charging. It will turn on as soon as USB power is connected.

Units made from July 2019 also have a charge socket next to the antenna connector. This is a three-pin header that a standard JR connector will plug into. The centre pin is positive and the two outer pins are negative. The header is directly connected to the battery so a standard LiPo charger can be used. The charging rate should be kept down to about 500 mA for these small batteries.

### Battery voltage indicator

The battery voltage is visible on the main menu and the flight screens.

- 4 -

## 4. Starting

When powered on, either by battery or USB, the unit will go through start-up stages dependent on its settings:

1. Power on screen
a. Startup
b. Wifi initialisation (if wifi enabled)
c. Bluetooth initialisation (if Bluetooth enabled)
2. Information screen – shows web server URL, wifi mode, Bluetooth status
3. Pressing the yellow button then shows the main menu


## 5. Navigation

There are three buttons used to navigate the system:

1. Red – flight reset
2. Yellow – menu item select
3. Green – menu item navigation and flight start

## 4. System Menus

### Main Menu

The main menu has the following (in Base Unit configuration the Setup Bases item is not present):

1. F3F Flights – flight menus
2. Setup Bases – base and camera unit selection
3. Options – setup options
4. Sleep – puts the unit into low power sleep mode. Use when charging.
5. Network Info – displays network connection information

### F3F Flights Menu

1. Practice Flights
2. Practice Laps
3. Contest Flights (not yet implemented)

### Options Menu

1. Volume – Cycles through 10 steps by pressing Yellow button
2. Unit Type – CD, Base A, Base B, Audio, or Wind (changing requires a restart)
3. Wifi – Client, AP, or Off (selecting goes to the wifi menu)
4. SSID – ID of the wifi to connect to (selectable from a stored list of five)
5. Bluetooth – On or Off (selecting goes to the Bluetooth menu)

- 5 -

### Bases Menu

Allows binding of base or camera units to use with the system.

Binding process

1. Ensure that the relevant base or camera unit is turned on
2. Select the unit in the Base menu. It will show ‘On’ and should also show ‘Linked’ to confirm that binding has been successful and then the signal strength (1-10).
3. This process only needs to be done once. The configuration is saved and subsequent use of the system uses the saved configuration.
4. Units should be deselected if they are not being used (‘-‘ shown next to unit name)

### Wifi Menu

The WiFi type can be selected to be one of:

- Client (UniTimer connects to an access point, e.g. a mobile phone hotspot)
- AP (UniTimer sets up its own access point)
- Off (Wifi is turned off)

A restart is necessary when switching Wifi modes

### Bluetooth Menu

The affects only the Bluetooth button operation. It has no effect on Bluetooth audio, which is always enabled (if fitted).

Bluetooth can be set to:

- On, or
- Off

The button type must be set. It is selectable between:

- iTAG button
- TrackerPA button

A restart is necessary when switching Bluetooth modes

### Signal indicator

A small Y or N will show in the bottom right of the display on the flights pages and setup menu. When using the unit as a base unit, this indicates connection to the central timing unit. Y=connected. N=not connected.

- 6 -

## 5. Wifi

### Wifi Modes

The unit has three wifi modes:

1. Client Mode – connects to a wifi access point, e.g. a router or phone set to be a mobile hotspot
2. AP Mode – runs its own access point that other devices can connect to
3. Off – wifi disabled

When in Client or AP mode, devices such as smart phones can connect to the unit’s web pages for information and configuration.

### Client Mode

If Client mode is selected then the unit will attempt to connect to a local wifi access point using saved credentials. These credentials are stored in a file on the system called ssids.csv. The details (SSID name and password) of up to five access points can be stored in the system. The access point to use is selected in the Options menu.

The first time the unit is used, it won’t have the access point credentials and will time out. You will then be presented with two options:

1. Press the green button to ignore Wifi
2. Press the red button to go to the Configuration Manager (see section on Configuration Manager below). This provides temporary connectivity to an access point.

### AP Mode

If AP mode is selected then the unit will start up its own access point called ‘F3X Timer’. To use this:

1. Use a wifi device, e.g. mobile phone to connect to the unit
2. On the phone wifi setup select ‘F3X Timer’ from the available wifi sources
3. In a web browser, enter 192.168.1.4 as the address to use

AP mode is the preferred method for setting up the client mode access point details.

Further details on setting up Wifi are available here:

https://github.com/simonwa2/F3X-Timing-System/wiki/F3X-Uni-Timer---wifi-modes

and:

https://github.com/simonwa2/F3X-Timing-System/wiki/F3X-Uni-Timer---configuring-for-multiple-wifi-access-points (https://github.com/simonwa2/F3X-Timing-System/wiki/F3X-Uni-Timer---configuring-for-multiple-wifi-access-points)

## 7. Bluetooth

Bluetooth can be used to connect a remote button (iTag or TrackerPA). The button is used to start/reset a flight (unit as CD) or signal a turn call (unit as a base).

The button type should be selected from the Bluetooth menu.

The button device should be turned on prior to turning on the unit with Bluetooth enabled. The system will try to connect for about 15 seconds. If that fails it will ignore Bluetooth.

This function is experimental and subject to connection failure.

- 7 -

## 8. Web Pages

The unit has a web server that provides web pages for controlling and viewing flights, and for configuring the system. The address to use is shown on the startup screen.

The web pages are in an early stage of development and are not fully functional, but the information shown on the pages is correct.

### Main page


### System Settings

Shows the current configuration for the bases and wifi. The wifi access points to use are set on this page


- 8 -

### Practice Flight

Lap times and Total flight time are shown as the flight progresses


- 9 -

## 9. Firmware Updates

Updating the firmware is done via a browser. There are two type of files that may need to be updated:

1. Firmware files. The actual code the unit runs. These all have a file extension of .bin, e.g. “F3X UniTimer vx.xx.bin”
2. Support files. The code for the web pages. These typically have a file extension of .mp3, .csv or .html.

Update files will be available from GitHub here:

https://github.com/simonwa2/F3X-Timing-System

Instructions for applying the updates are contained within each version’s page.

- 10 -

## 10. Base Unit Operation

If configured as a base unit, the menus are only slightly different, e.g. no Base Setup option. The unit will automatically go into the correct flight mode once the CD unit goes to an F3F flight start screen.

Signalling a turn can be done in three ways:

1. Pressing the Red button
2. Using a Bluetooth button
3. Connecting an external switch to the expansion port (D1)

## 11. Expansion Port

The expansion port provides for the following:

1. Two external switches – e.g. a base turn switch on D1
2. Anemometer (not yet implement in software)
a. Davis 6410, or
b. Peet Bros Ultimeter Pro
3. External alarm/buzzer (not yet implemented in software)

### Connector pins (left to right):

1. Ground
2. 3.3V (for Davis anemometer only)
3. Relay – open collector output for driving a relay for an external buzzer
4. D2 – digital input for anemometer
5. D1 - digital input for anemometer or external switch
6. A1 – analog input for Davis wind direction

- 11 -

## 12. F3F flights

### Practice Flights

Practice Flights provide full timing but are not saved to storage (currently). The sequence for a flight is the following stages:

1. Ready. Press Green button (or Bluetooth iTag) to start.
2. Pre-Launch. 30 second pre-launch countdown. Press Green button (or Bluetooth iTag) to launch.
3. Launched. 30 second climb-out countdown.
4. Out of Course. When signal received from base A, or Green button pressed
5. Started. When entered the course as signalled by Base A or Green button pressed
6. Lap counts
7. Finished

To reset a flight, press the Red button at any point of the flight, or the iTag once the flight is at Launched stage or later.

Manual or automatic start of the next flight can be set on the F3F Flights menu. The options are 10s, 15s, 20s, 30s or manual start. If an auto start time is selected then, at the end of a flight, a pre-launch countdown will commence. This gives the pilot time to fly back to the centre of the course n time to get the Launched signal and commence the 30s climb-out to start the flight,

To return to the Flights menu, press the Yellow button in the flight Ready stage.

### Practice Laps

Practice laps provides for continuous laps, with the individual lap time called out. This allows testing of different turn techniques. Press Green button to start. Red button to Reset.

### Contest Flights

Currently this is not implemented. It will provide for full contest timing.

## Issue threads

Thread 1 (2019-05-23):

Uni-Timer bluetooth for iTag button fails to work in V1.0.1

simonwa2, 2019-05-23:
Bluetooth connection to iTag button does not work in Uni-Timer V1.0.1.

It did work in V1.0.0.  Changes made to how webserver operates (now uses websockets), may have caused conflict between wifi and bluetooth.

Too be investigated

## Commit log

2019-05-17 Create Uni-Timer V1.0.1 Release Notes
2019-05-17 Update Uni-Timer V1.0.1 Release Notes
2019-05-26 Create Uni-Timer V1.0.2 Release Notes
2019-06-01 Create Uni-Timer V1.0.3 Release Notes
2019-06-01 Update Uni-Timer V1.0.3 Release Notes
2019-07-19 Create Uni-Timer V1.0.5 Release Notes
2019-07-20 Update Uni-Timer V1.0.5 Release Notes
2019-07-26 Create Uni-Timer V1.0.6 Release Notes
2019-07-26 Update Uni-Timer V1.0.6 Release Notes
2019-11-20 Refreshed with new version
    Fixes a couple of small bugs in the release
2020-04-19 Updated external switch info
2020-04-19 Updated external switch (D1 an D2) functions
